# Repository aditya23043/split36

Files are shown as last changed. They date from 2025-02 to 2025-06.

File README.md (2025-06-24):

# 36 Key Split Ergonomic Keyboard

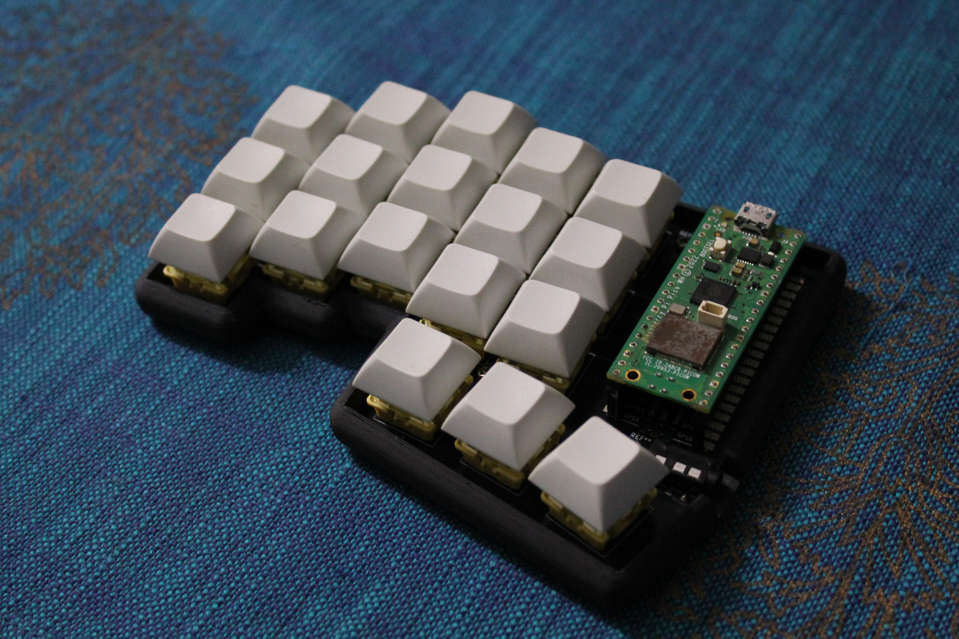
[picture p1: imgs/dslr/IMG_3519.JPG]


## Block Diagram



## BOM

| Item | Qty | Total Price | Ordered From |
| --- | --- | --- | --- |
| PCB | 2 | ₹ 800 | Robu.in |
| 3D printed Cases (optional but recommended) | 2 | ₹ 652 | Robu.in |
| Akko V3 Creamy Yellow Pro Mechanical Switch | 45  | ₹ 999 | StacksKB.com |
| 3.5mm TRRS Jack | 2 | ₹ 28 | Robu.in |
| Raspberry Pi Pico | 2 | ₹ 700 | Robu.in |
| Header 1x40 pin | 2 | ₹ 14.6 | Robu.in |
| High Quality Ultra Flexible 30AWG Silicone Wire - Black | 5 | ₹ 25.00 | Robu.in |
| M2 X 6mm Brass Threaded Inserts (Dia. 2mm, Length 6mm) | 12  | ₹ 26.40 | OnlyScrew.in |
| M2 X 6mm Phillips Pan head SS 304 Screw (Dia. 2mm, Length 6mm) | 12  | ₹ 24.00 | OnlyScrew.in |
| Total | - | ₹ 3269 | |

## Order

<details>
<summary>All the stuff ordered in regards to this project</summary>

> This is not the actual concise BOM\
> All this is just the stuff I ordered related to this project

- StacksKB.com

  - Akko V3 Creamy Yellow Pro Switch (Pack of 45) × 1
  - Order Number: 30456
  - Cost: 899 + 100 (delivery) = ₹ 1000
  - Order Date: 2025-02-08

- Robu.in

| Item | Qty | Cost  |
| --- | --- | ----- |
| TRRS Jack | 2 | ₹ 28  |
| Raspberry Pi Pico | 1 | ₹ 349 |
| Header 1x40 pin | 12  | ₹ 88  |
| Ball Bearing | 2 | ₹ 38  |
| Handling charges  | - | ₹ 25  |
| TOTAL | - | ₹ 528 |

- Robu.in (2nd)

| Item | Qty | Cost |
| --- | --- | --- |
| USB 3.1 Female Socket Type C Connector 24 Pins Breakout PCB Board | 2 | ₹ 98.00 |
| Wire Stripper Flat Nose Cable Cutter with Practical Punch Down Tool | 1 | ₹ 18.00 |
| High Quality Ultra Flexible 30AWG Silicone Wire - Black | 5 | ₹ 25.00 |
| UL1007 26AWG PVC Electronic Wire - Black | 2 | ₹ 14.00 |
| High Quality Ultra Flexible 22AWG Silicone Wire - Black | 2 | ₹ 36.00 |
| Heat Shrink Sleeve 1mm Red Industrial Grade WOER (HST) | 4 | ₹ 20.00 |
| Piezo Buzzer 35mm | 1 | ₹ 16.00 |
| Subtotal: | - | ₹ 227.00 |
| Shipping: | - | ₹ 49.00 via STANDARD SHIPPING |
| Cash Handling Charges: | - | ₹ 25.00 |
| Total: | - | ₹ 301.00 |

- OnlyScrew.in

| Item | Qty | Cost |
| --- | --- | --- |
| M2 X 6mm Brass Threaded Inserts (Dia. 2mm, Length 6mm) | 12  | ₹ 26.40  |
| M2 X 4mm Phillips Pan head SS 304 Screw (Dia. 2mm, Length 4mm) | 12  | ₹ 21.60  |
| M2 X 3mm Brass Threaded Inserts (Dia. 2mm, Length 3mm) | 12  | ₹ 19.20  |
| M2 X 6mm Phillips Pan head SS 304 Screw (Dia. 2mm, Length 6mm) | 12  | ₹ 24.00  |
| M2 Hex Nut SS304 (Dia. 2mm) | 12  | ₹ 19.20  |
| M3 X 12mm Phillips CSK SS 304 Screw (Dia. 3mm, Length 12mm) | 10  | ₹ 16.00  |
| Allen Key 2mm Chromium Vanadium Steel | 1 | ₹ 6.20 |
| M3 X 12mm Hex (Allen) Button Head SS 304 Screw (Dia. 3mm, Length 12mm) | 8 | ₹ 17.60  |
| Subtotal | - | ₹ 150.20 |
| Shipping | - | ₹ 99.00  |
| Taxes | - | ₹ 27.04  |
| Total | - | ₹ 276.24 |

</details>

## Case Designing

- I am aiming for a sandwich case which consists of a bottom part, middle part for padding, another plate in which pcb is resting and the top switch mount plate
- The bottom plate will be of 3mm ABS (non metal laser cut) so that the keyboard has a solid base
- The next plate is the middle one but it is a little bit smaller in inner part so that the PCB can rest on top of it
  - this plate's height will be -> 3mm because we need at least (3.3-1.6) = 1.7mm clearance and having another 1.3mm would be nice so that the soldered wires can go through
  - note: 3.3mm is the distance between the bottom-most point of the MX switch and the point which rests on the PCB
  - and the height of the PCB is 1.6mm
- Next is the other bottom plate with the pcb cutout in the middle so that the pcb can be put into it and also provides the gap between the previous middle layer and the switch mount plate
  - This will be of height -> (5-1.5)+(1.6) = 5.1mm
- Lastly, we have the switch mount plate which obviously holds the MX switches and needs to be 1.5mm in height



## Materials Used for the case (complex case)

| Plate | Material | Cost |
| --- | --- | ---- |
| Bottom | Laser cut Acrylic 3mm |
| Middle | Laser cut Acrylic 3mm |
| Middle v2 | Laser cut Acrylic 5mm |
| Top | ABS FDM 3d printed |

> As of now (025-02-19 23:20), I am pausing this sandwich case idea and shifting to just a single case which encloses the PCB from the bottom and sides\
> I would have preferred to have a switch mount plate as well because it adds stability and reduces dust residue in the keyboard but I would like to get started with a simpler case than the sandwich one and also, I would like to use the existing mounting stuff I have bought i.e. the m2x3mm brass inserts and hence I am heading for this approach

## Simple Case

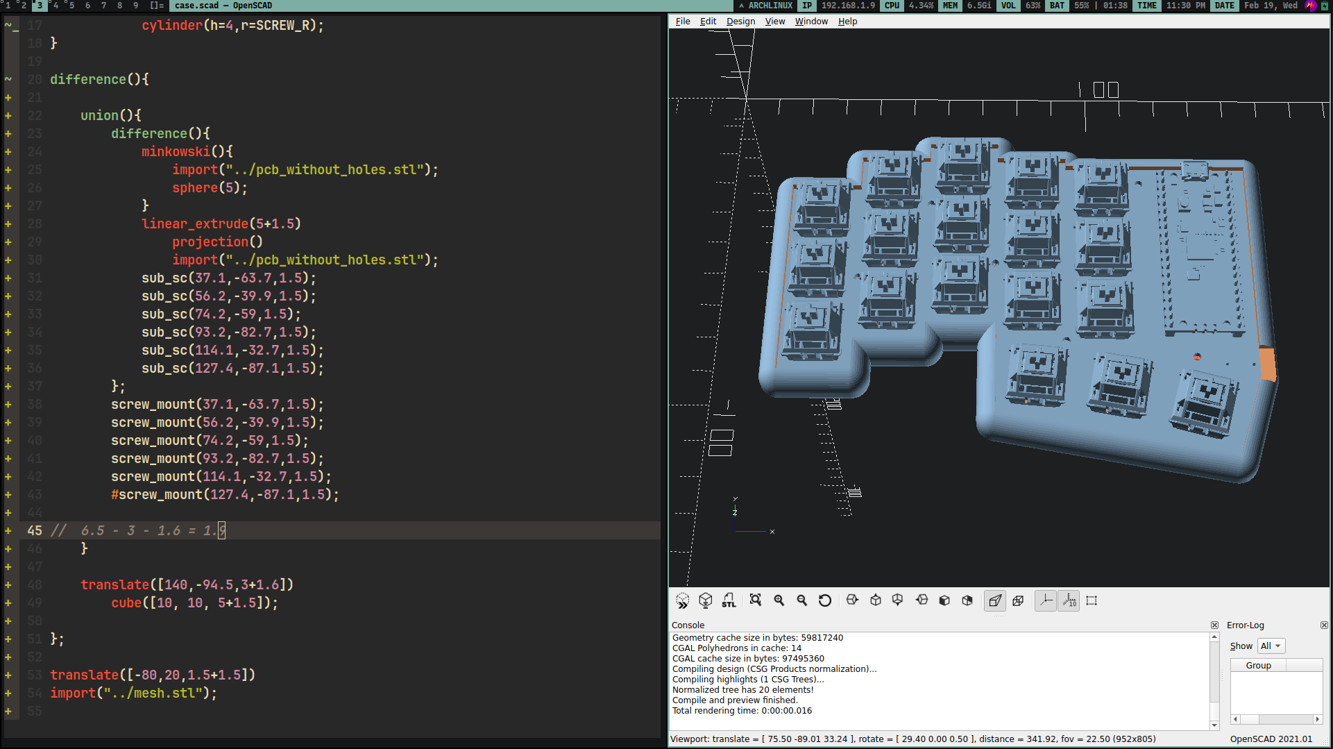
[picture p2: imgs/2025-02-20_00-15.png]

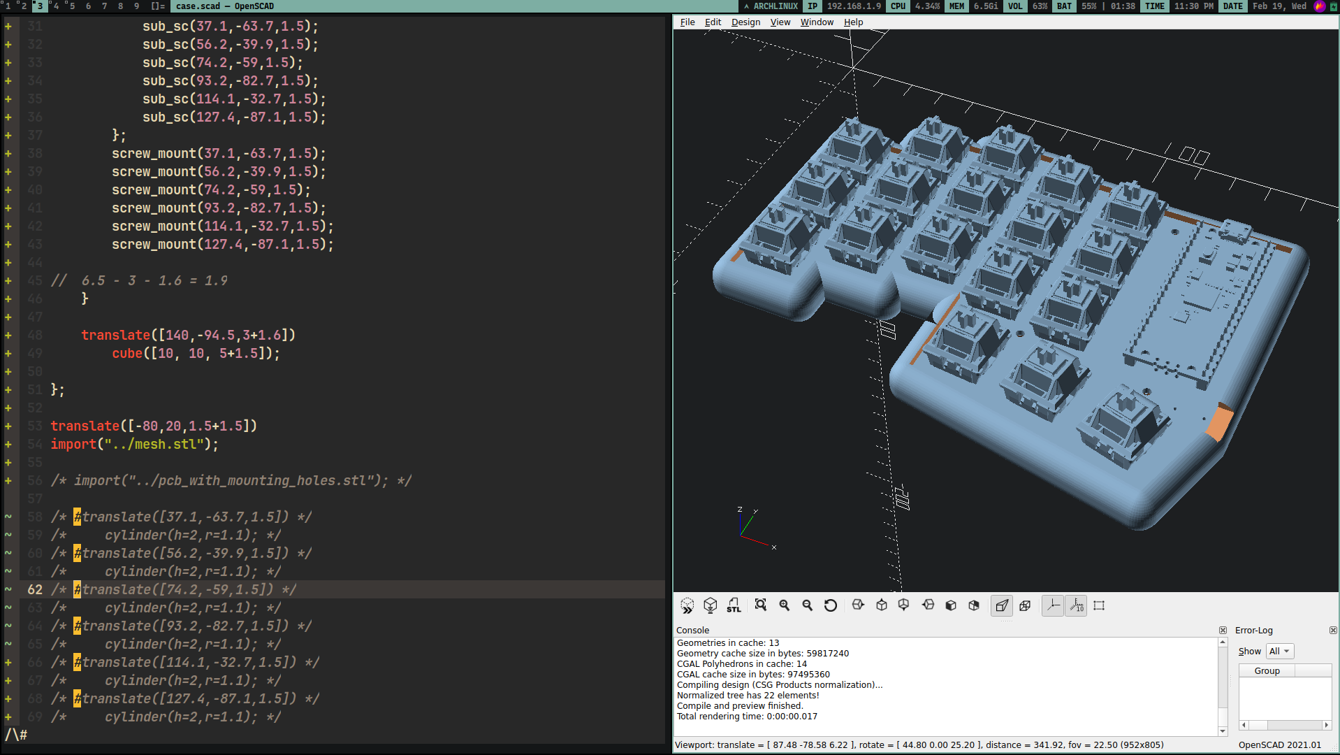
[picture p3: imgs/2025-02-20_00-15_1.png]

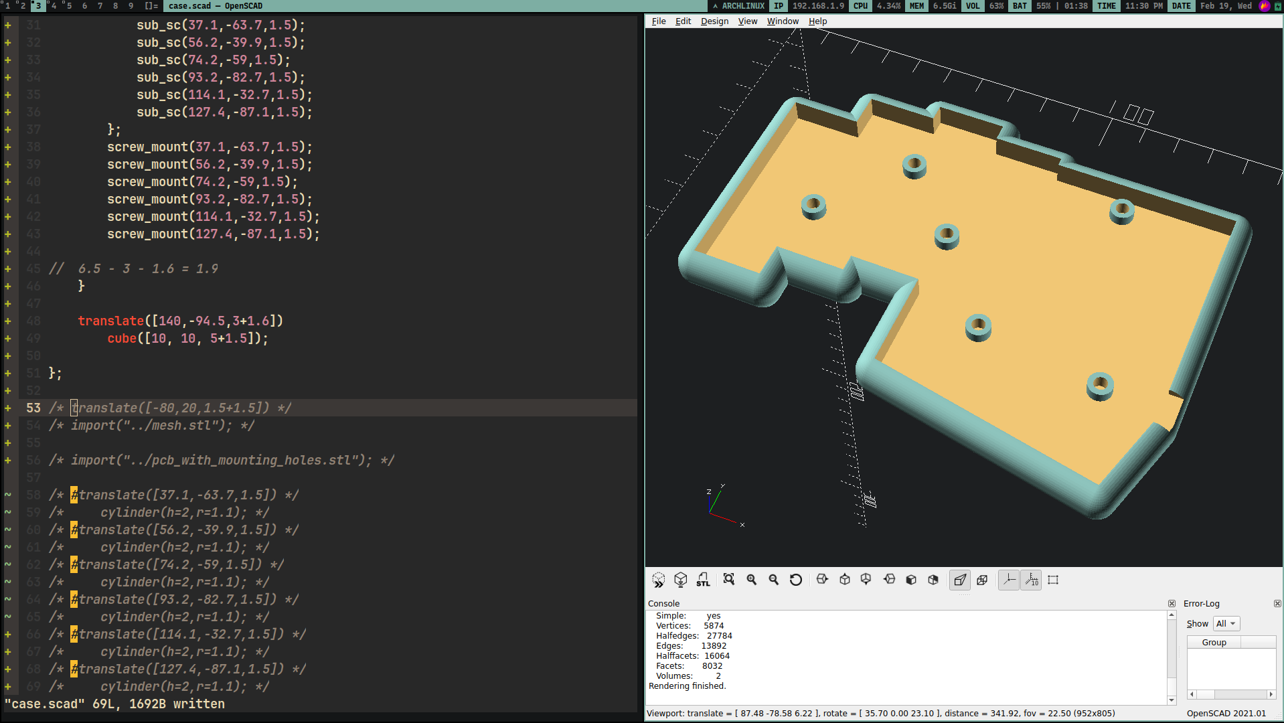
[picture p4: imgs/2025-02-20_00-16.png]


- This case was costing me about Rs. 389 on https://robu.in with ABS and 15% infill
- I believe that is a bit high for me since this is just half of the keyboard
- So, I reduced the cost down to about Rs. 300 by putting the PCB a bit lower and instead of the 5mm solid base, we now have a 2mm solid base which makes a little bit less solid but its not a huge problem
- This is the case with the PCB after the cost cut

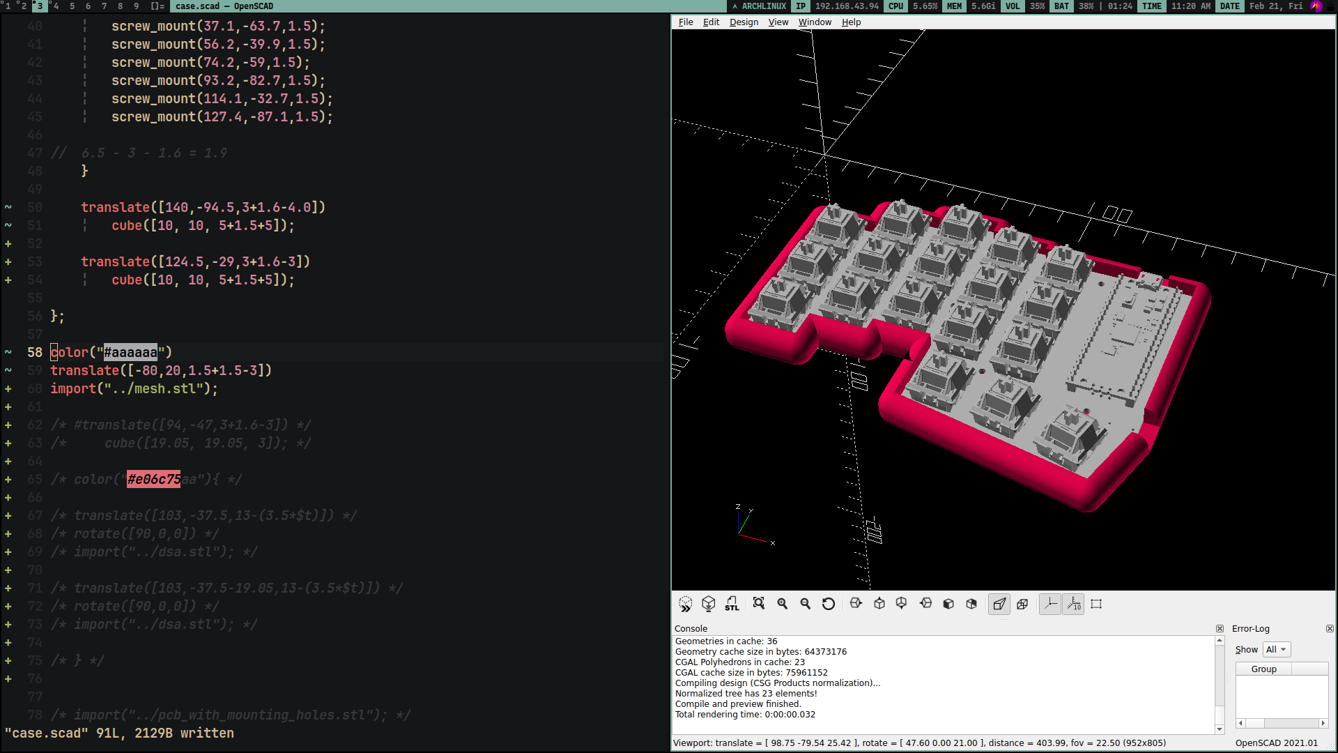
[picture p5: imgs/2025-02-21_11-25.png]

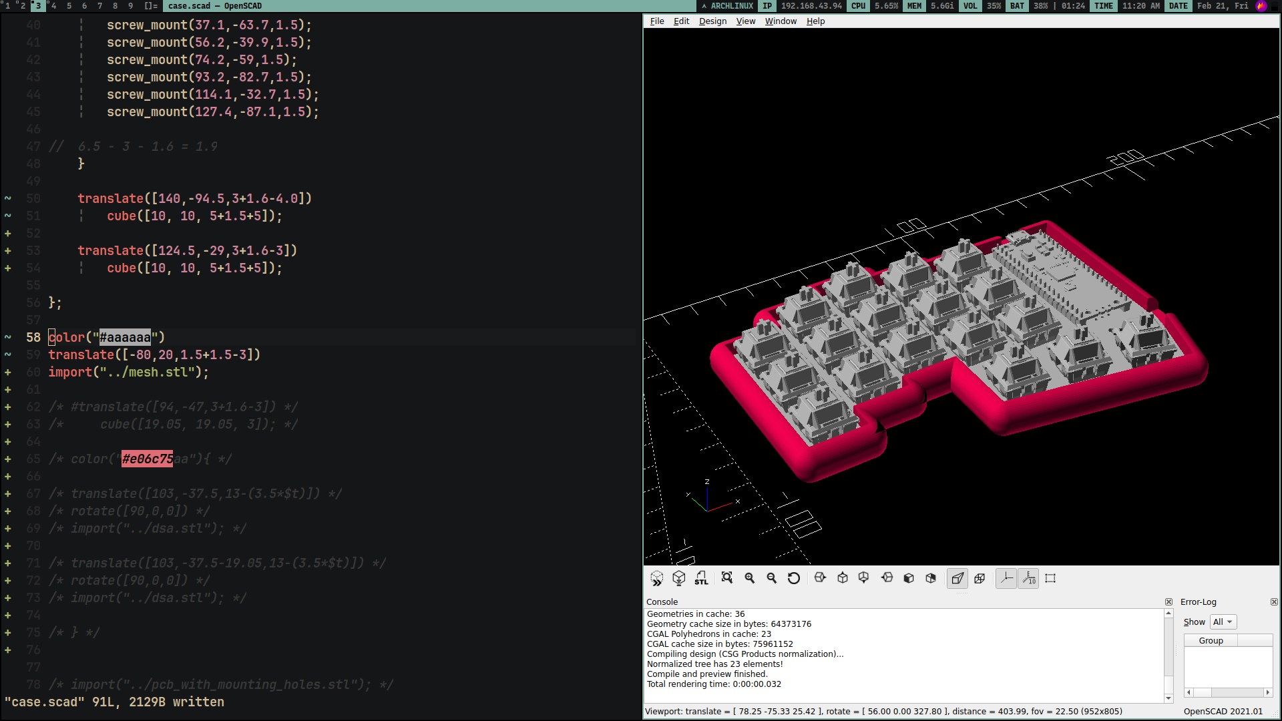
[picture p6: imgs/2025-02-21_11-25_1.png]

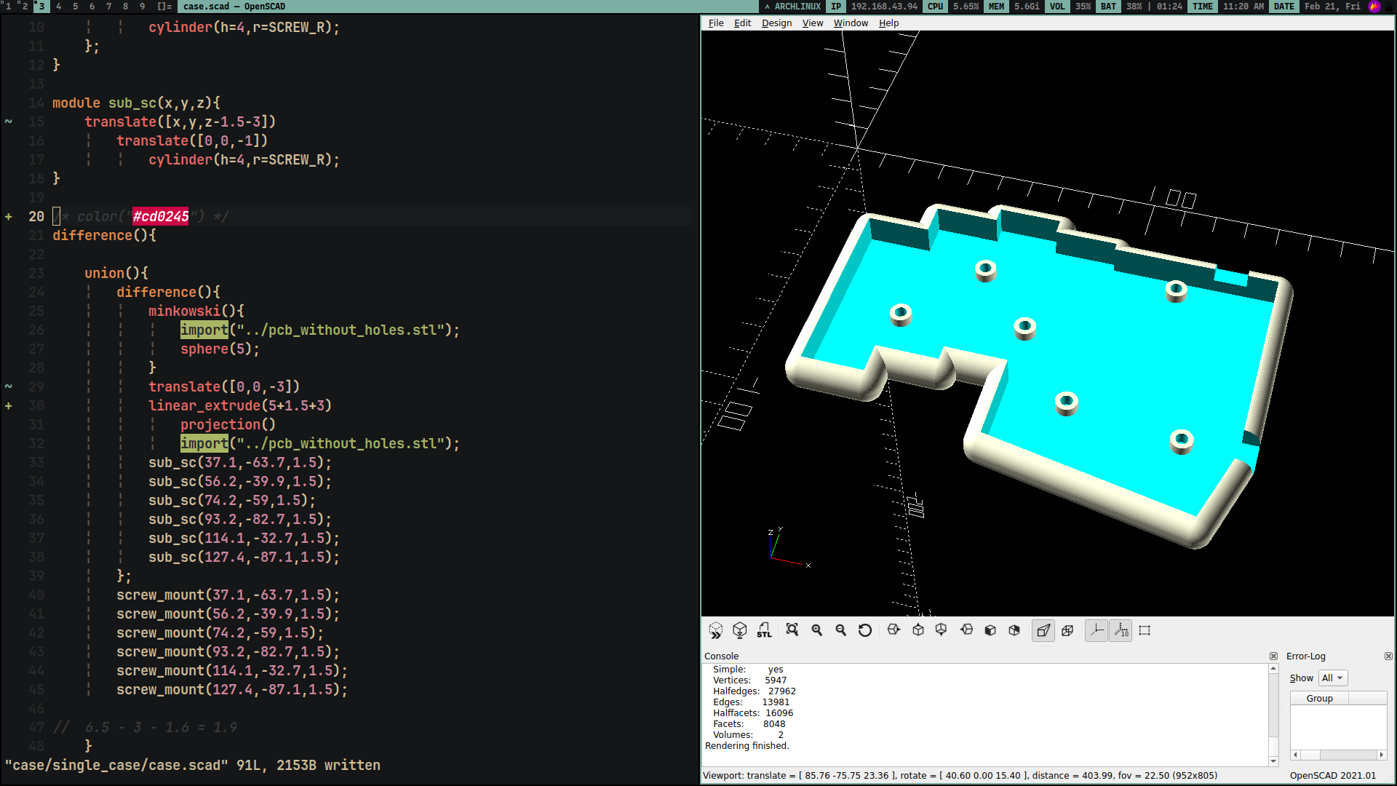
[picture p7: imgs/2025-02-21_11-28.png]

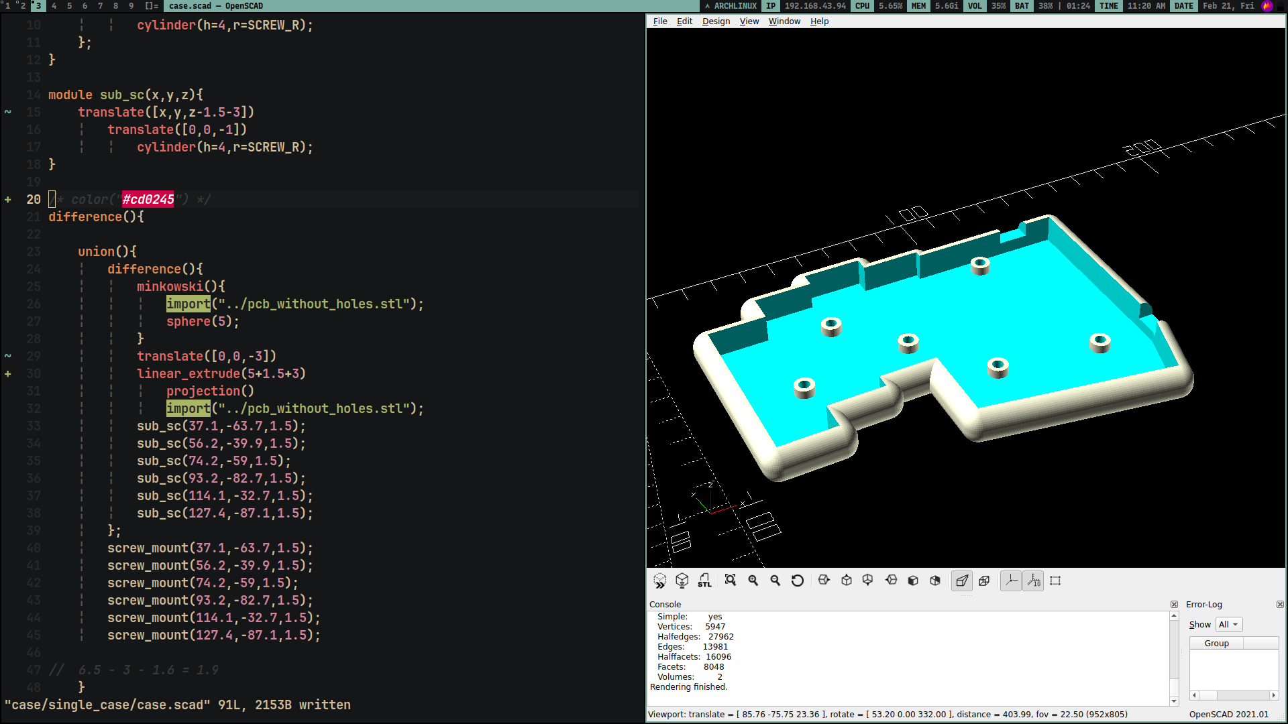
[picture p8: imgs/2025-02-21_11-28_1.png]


- Order placed for this case for Rs.335 along with the mount plate for this project -> https://github.com/aditya23043/Tekken_Controller
- Totalling: Rs. 463 (335 + 79 (mount plate) + 49 (delivery))

## 2025-02-26 23:54

- The case has arrived for one of the halves since I wanted to make sure there were no issues with my design
- And guess what? Yes, there is a major issue with the design
- I had not taken printing error in mind and hence did not account for tolerance issues
- The PCB just wont go in flush. It seems like if the case was just 0.5-1mm more larger on the inside, the PCB would have rested perfectly
- I have updated the 3D case files in the repo to include a 0.7mm clearance on the inside
- As for the case, I have taken suggestions from seniors and batchmates from the Electroholics Club of IIITD
- They have suggested to either use the thermal property of ABS in order to mould it into a bit bigger enclosure
- Or sand the edges down a bit to accomodate the PCB perfectly
- I will be taking the latter approach since that seems more fail proof in my mind
- And hence, I have ordered this sand paper set from amazon -> [Sand paper](https://www.amazon.in/Abrasive-Automotive-Woodworking-Furniture-Finishing/dp/B0CCW1BG6J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)

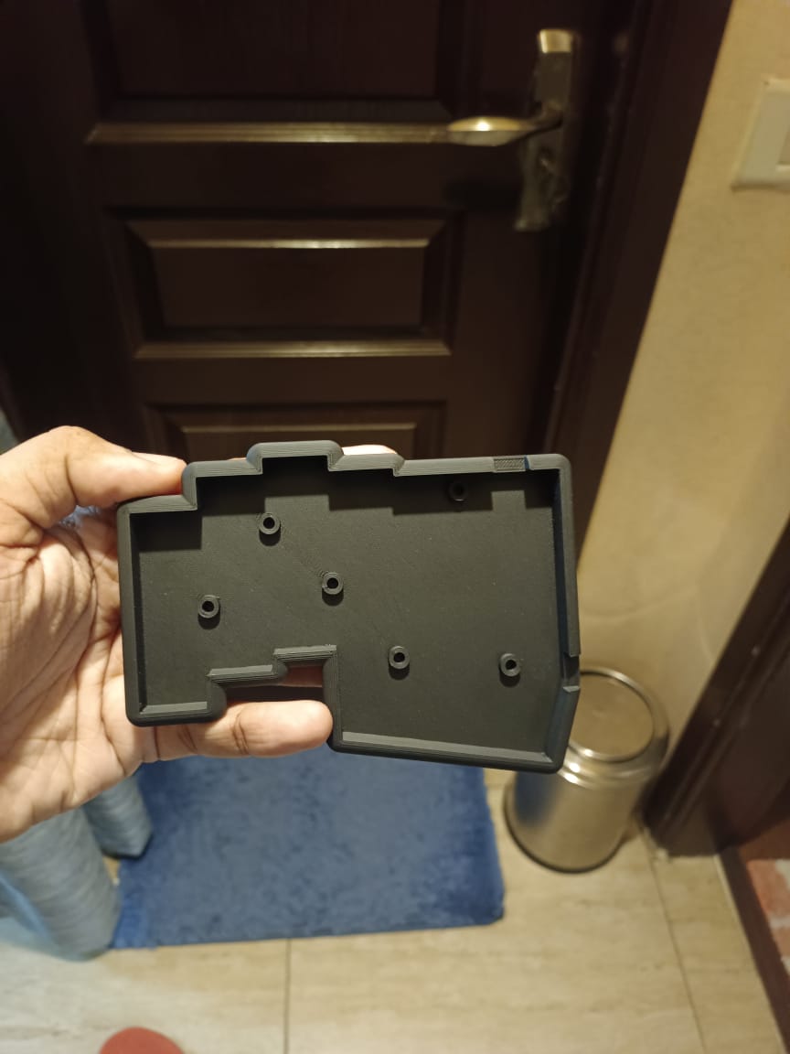
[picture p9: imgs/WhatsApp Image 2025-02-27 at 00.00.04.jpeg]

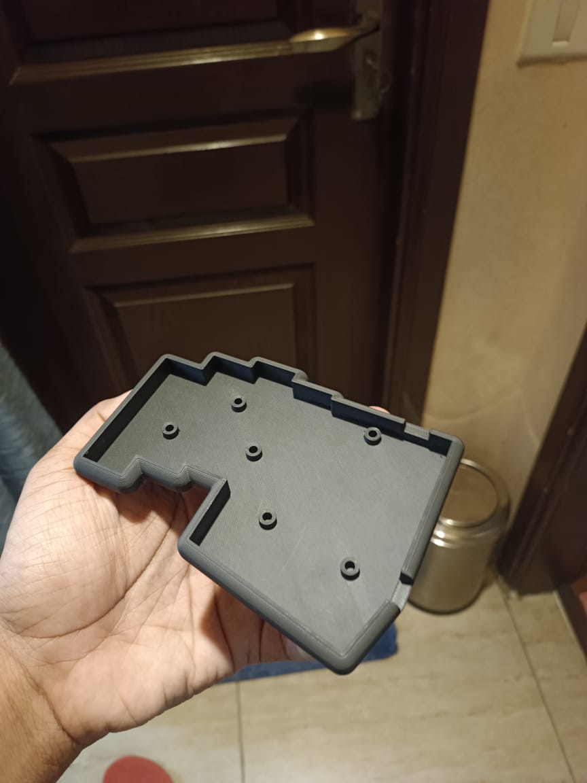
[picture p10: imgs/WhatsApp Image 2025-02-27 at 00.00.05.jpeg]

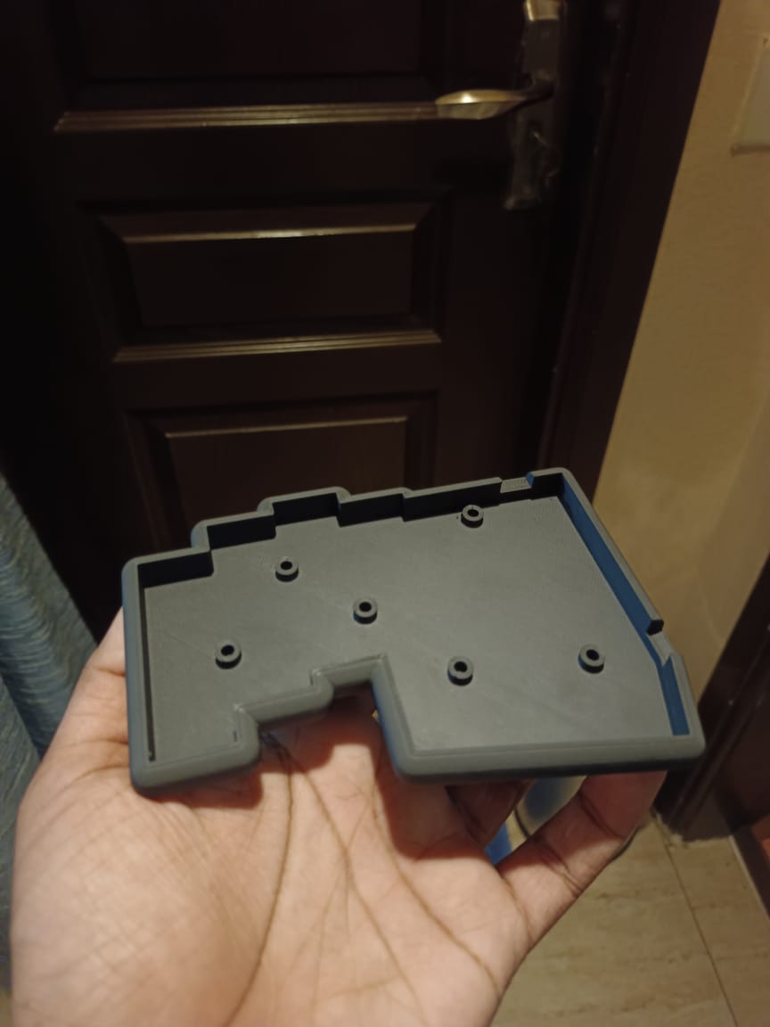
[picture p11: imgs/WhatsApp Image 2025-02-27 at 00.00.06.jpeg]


## 2025-03-18 23:48

- Instead of trying to make do with the case without tolerances, I have decided to add 1mm tolerance to the current design and order it again
- For ABS 15% infill 2mm default nozel, it is costing me Rs. 277 + Rs. 49 = Rs. 326

## 2025-03-29 00:23

- Added brass heat inserts in order to mount the pcb to the case using M2 screws
- Finished soldering the mechanical switches, header pins for MCU and the TRRS jack onto the PCB.

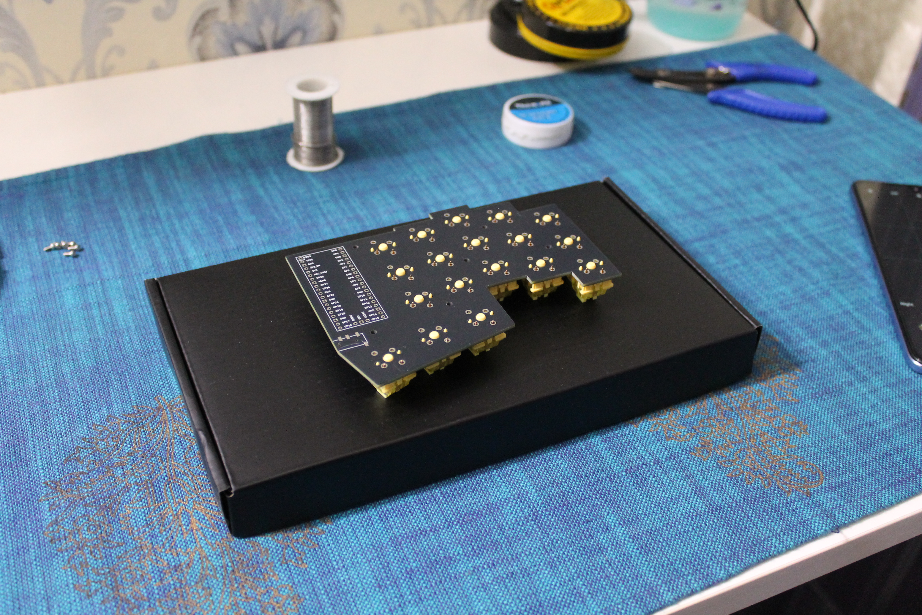
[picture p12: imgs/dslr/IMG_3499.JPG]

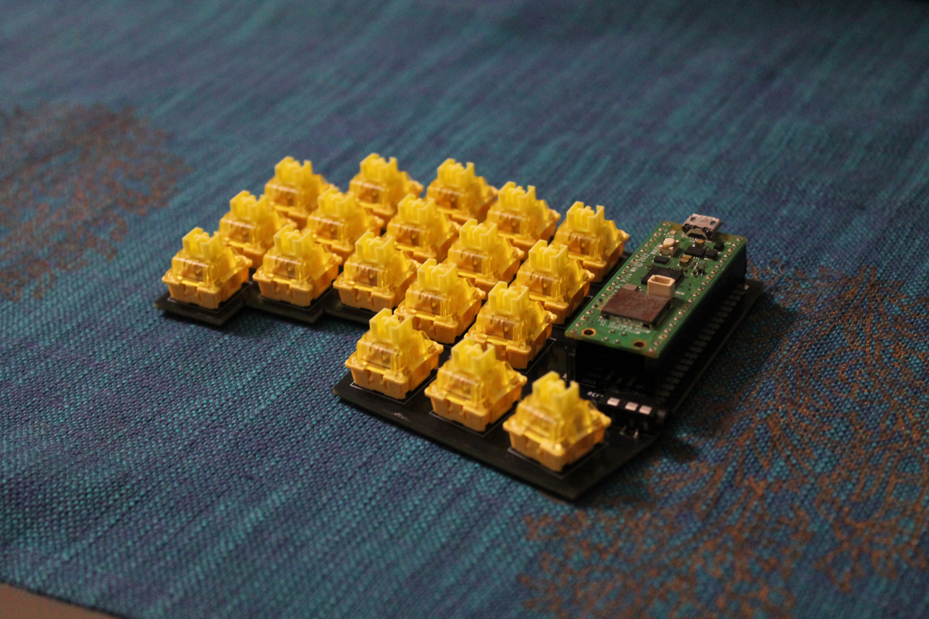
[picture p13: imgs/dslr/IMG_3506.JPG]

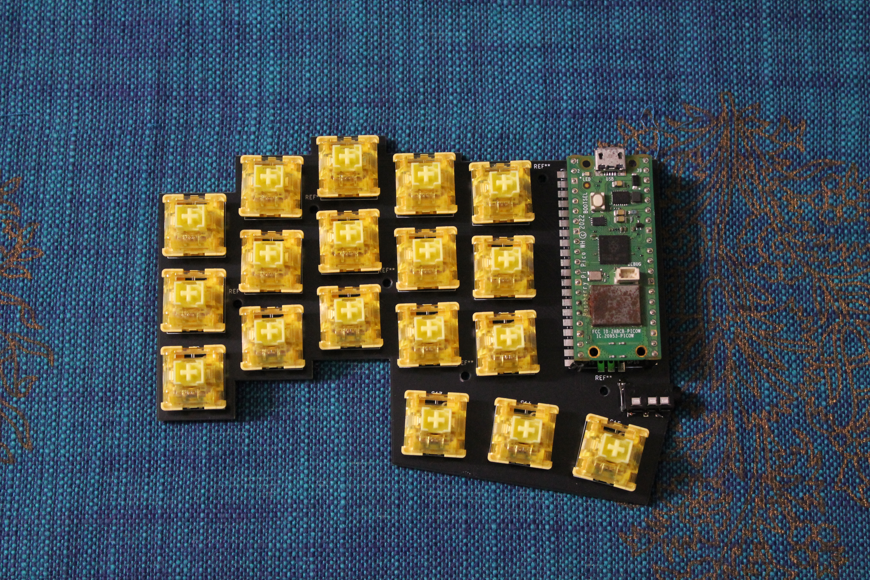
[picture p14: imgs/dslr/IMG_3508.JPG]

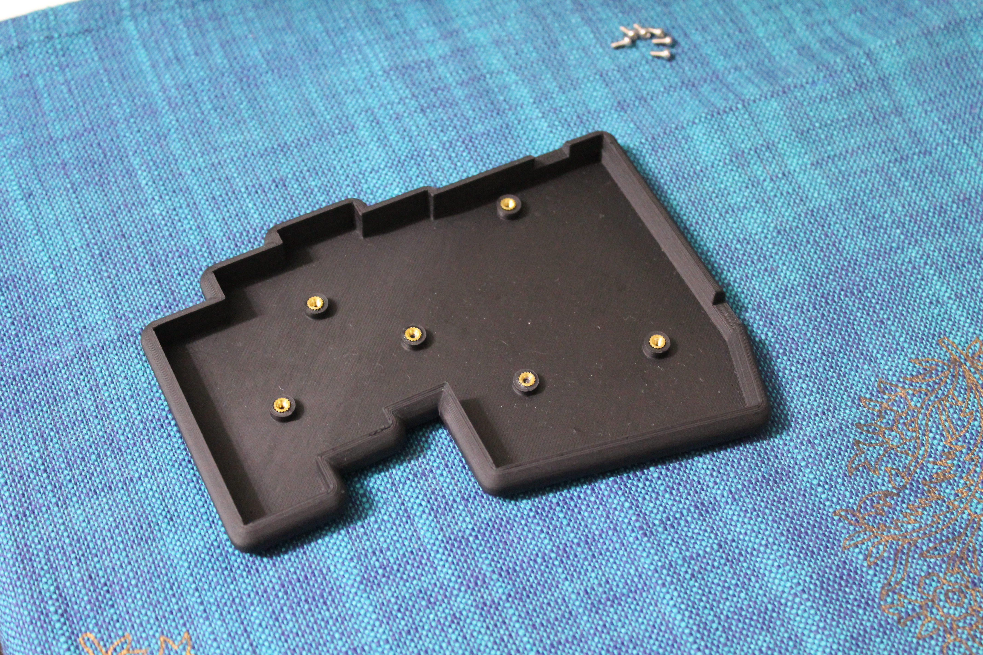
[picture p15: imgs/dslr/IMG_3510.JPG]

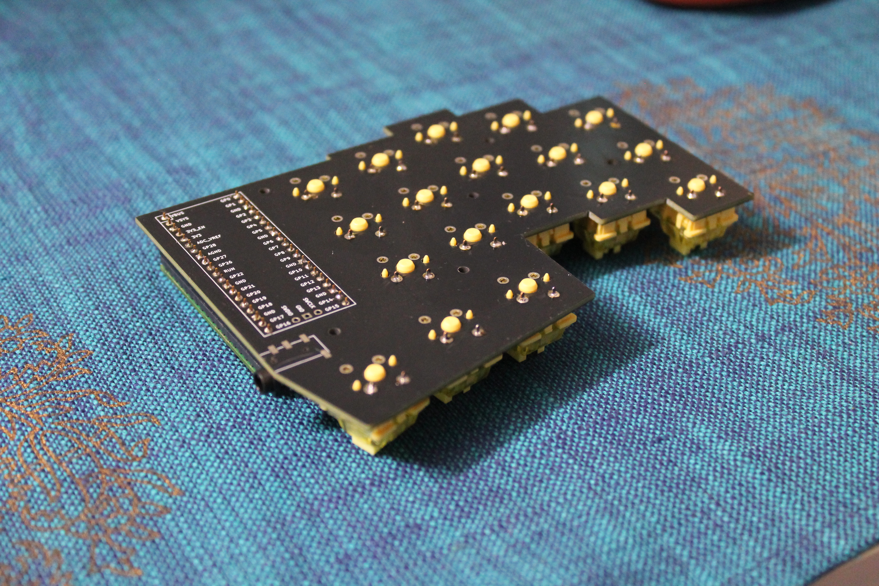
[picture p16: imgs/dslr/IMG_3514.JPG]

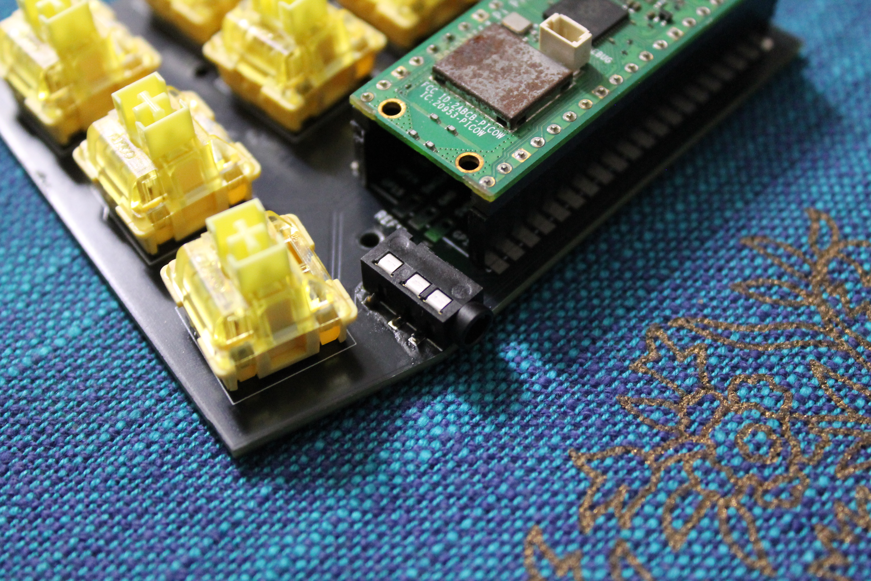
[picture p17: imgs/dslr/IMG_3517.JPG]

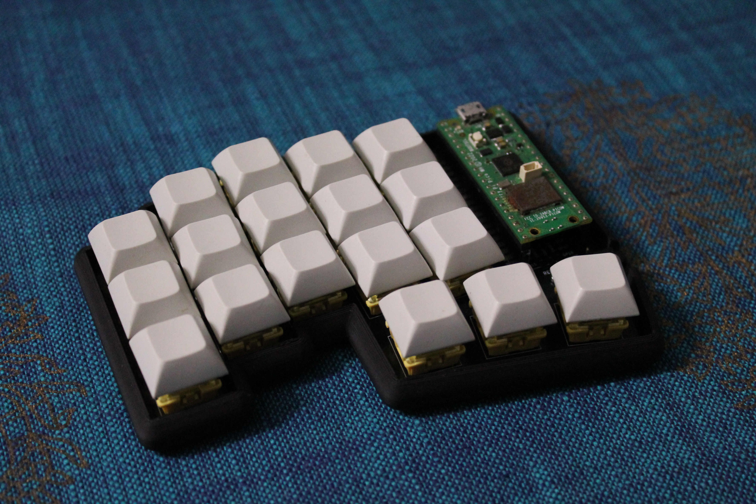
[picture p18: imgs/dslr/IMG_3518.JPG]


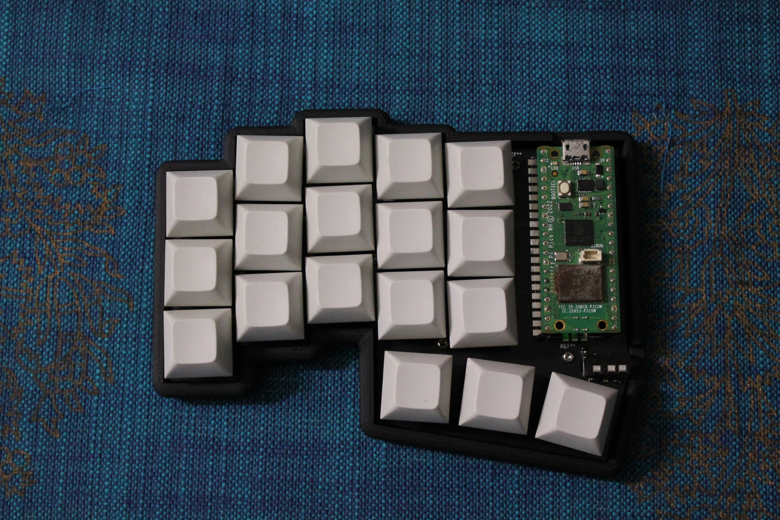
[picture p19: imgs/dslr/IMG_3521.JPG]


## 2025-03-31 23:45

- Deep purple keycaps came in today
- Fixed the skew in keyswitches -> https://www.reddit.com/r/ErgoMechKeyboards/comments/1jmeygr/the_switches_on_my_custom_cornelike_keyboard_do/

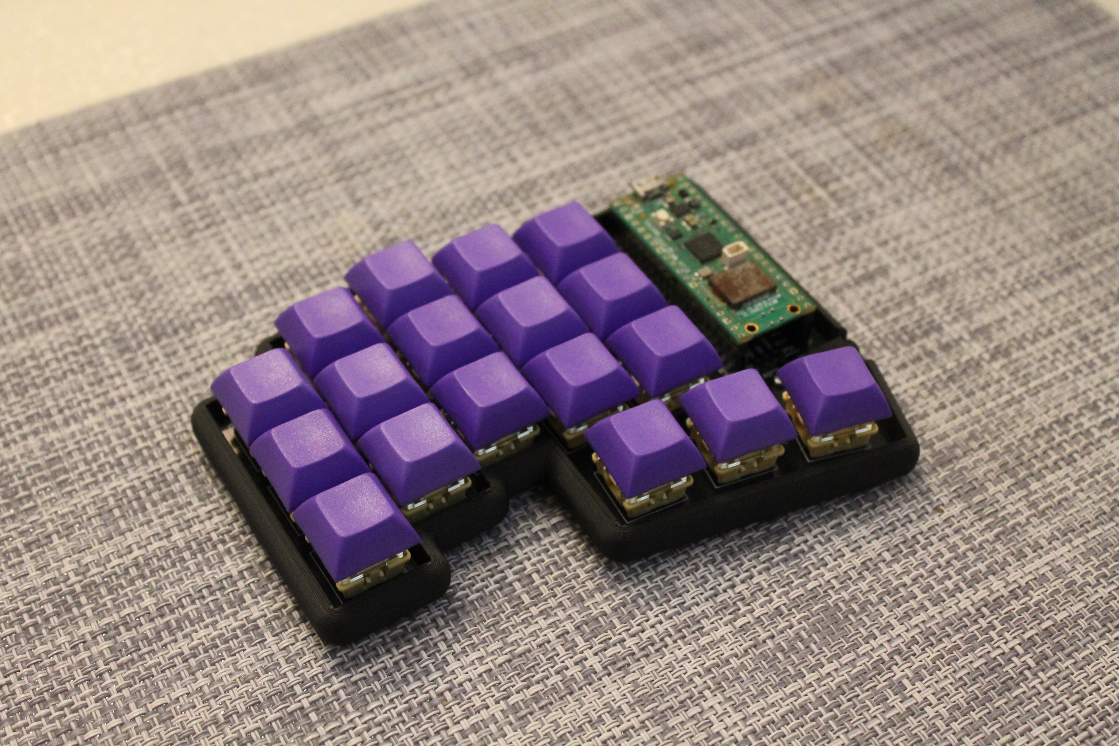
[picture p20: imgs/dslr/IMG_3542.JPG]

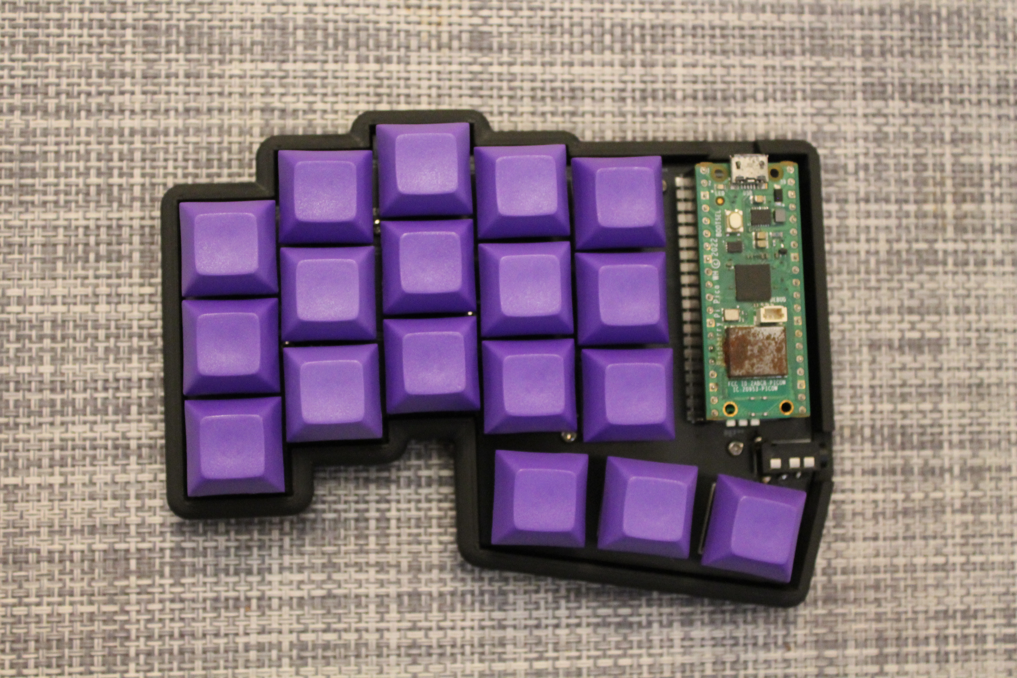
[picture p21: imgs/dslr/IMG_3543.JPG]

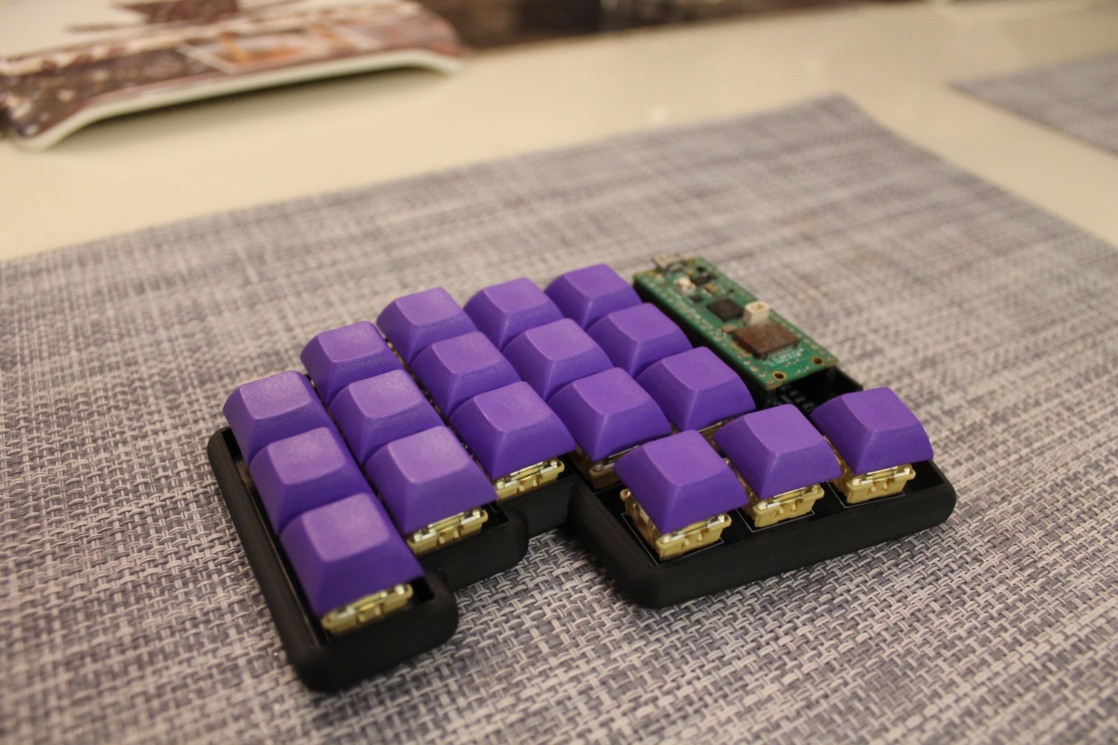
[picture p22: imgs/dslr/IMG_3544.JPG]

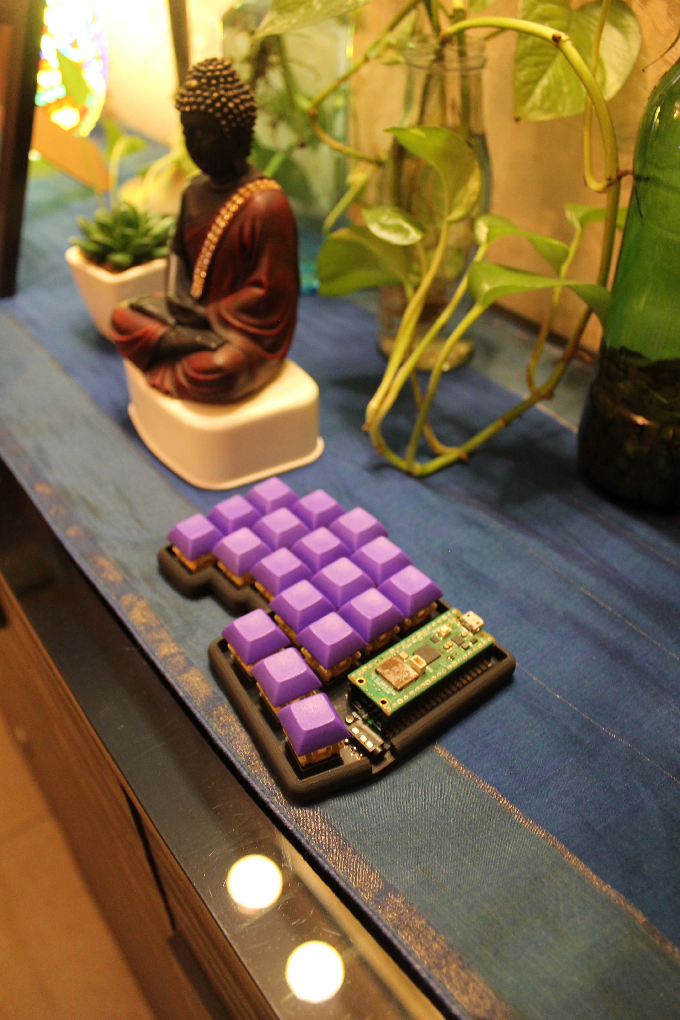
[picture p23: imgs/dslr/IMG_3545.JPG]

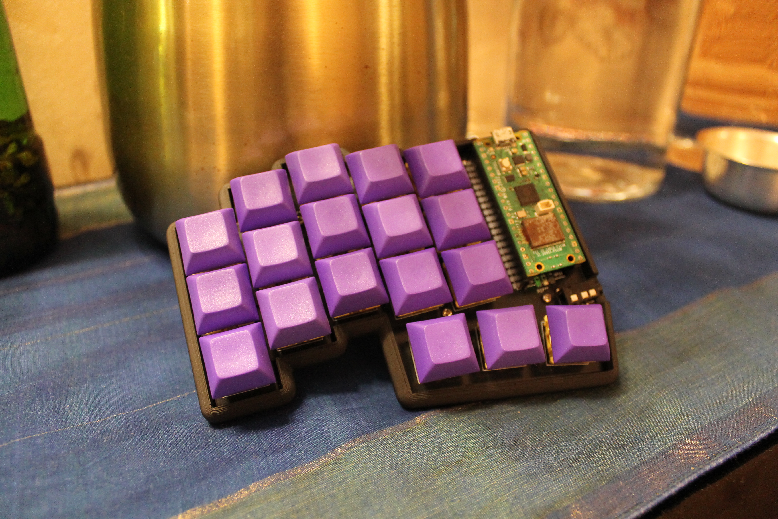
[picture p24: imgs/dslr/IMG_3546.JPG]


## 2025-03-05 10:03

- Case for the right half ordered from https://Robu.in
- Firmware for the left half done
  - Also includes the code for "key held down" event
- [x] Right half assembly
- [ ] Right half firmware

## 2025-04-11 23:13

### Major Issue

- The footprint used for the MX switches (from ScottoKeeb's github repo) had label -> MX 1.00u Reversible written on it. However, it means reversible in the sense that we can swap north facing and south facing switches, not for mutli sided switches
- Hence, the assembly of the right half is on hold until the new PCB arrives.
- In the modified kicad project I have used the SW_MX_REVERSIBLE footprint from -> https://github.com/daprice/keyswitches.pretty
- Furthermore, I have added the kicad project in this repo inside the `pcb/` directory
- 2025-04-11 23:26 -> PCB order placed
  - Cost: ₹1935 for 5 PCBs
  - Nearly: ₹400 per PCB

## 2025-05-03 23:13

- Right Half assembly done

## Major Issue 2.0

- The TRRS jack connection on the second half is technically correct but the problem is that since the right half is just the flip of left half PCB, the microcontroller should either be soldered reverse or else the pins are flipped wrt the vertical axis
- Due to this, the connections of the TRRS jack are reversed as well
- Instead of GND, VSYS, GP0, GP1; we have -> GND, GP1, VBUS, VSYS which is very wrong in context of the code logic
- Hence, I had to scratch out all the copper tracks manually connected to the TRRS jack and connect them with the MCU manually using wires with the following connections

```
TRRS
4 3 2
    1

DEFAULT
1 GND
2 GP1
3 VBUS
4 VSYS

WHAT WE WANT
1 GND
2 VSYS
3 GP0 (SDA)
4 GP1 (SCL)
```

- And finally, with testing, I am able to confirm that the right half can now be powered properly with just the left half connected with the system
- So, as of now, this prototype's hardware stuff has been completed
- [X] TODO: Firmware

WhatsApp Image 2025-05-03 at 23 23 26
WhatsApp Image 2025-05-03 at 23 23 26(1)
WhatsApp Image 2025-05-03 at 23 23 26(2)
WhatsApp Image 2025-05-03 at 23 23 29
WhatsApp Image 2025-05-03 at 23 23 30

# Finished the project! 
- Presentation: https://docs.google.com/presentation/d/1XDV15suqviizSQfUHfM2_ha1iqeUGhER_RJtFe0Dyr4/edit?usp=sharing
- LinkedIn Post: https://www.linkedin.com/posts/aditya23043_just-completed-my-most-ambitious-project-activity-7335380768921198593-B5wh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

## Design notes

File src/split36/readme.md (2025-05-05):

# split36

split36

*A short description of the keyboard/project*

* Keyboard Maintainer: [Aditya Gautam](https://github.com/aditya23043)
* Hardware Supported: *The PCBs, controllers supported*
* Hardware Availability: *Links to where you can find this hardware*

Make example for this keyboard (after setting up your build environment):

    make split36:default

Flashing example for this keyboard:

    make split36:default:flash

See the [build environment setup](https://docs.qmk.fm/#/getting_started_build_tools) and the [make instructions](https://docs.qmk.fm/#/getting_started_make_guide) for more information. Brand new to QMK? Start with our [Complete Newbs Guide](https://docs.qmk.fm/#/newbs).

## Bootloader

Enter the bootloader in 3 ways:

* **Bootmagic reset**: Hold down the key at (0,0) in the matrix (usually the top left key or Escape) and plug in the keyboard
* **Physical reset button**: Briefly press the button on the back of the PCB - some may have pads you must short instead
* **Keycode in layout**: Press the key mapped to `QK_BOOT` if it is available

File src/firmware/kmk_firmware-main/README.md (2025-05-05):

# KMK: Clackety Keyboards Powered by Python






KMK is a feature-rich and beginner-friendly firmware for computer keyboards
written and configured in
[CircuitPython](https://github.com/adafruit/circuitpython).

## Support

For asynchronous support and chatter about KMK, [join our Zulip
community](https://kmkfw.zulipchat.com)!

If you ask for help in chat or open a bug report, if possible
make sure your copy of KMK is up-to-date.
In particular, swing by the Zulip chat *before* opening a GitHub Issue about
configuration, documentation, etc. concerns.

> The former Matrix and Discord rooms once linked to in this README are no
> longer officially supported, please do not use them!

## Features

- Fully configured through a single, easy to understand Python file that lives
  on a "flash-drive"-esque space on your microcontroller - edit on the go
  without DFU or other dev tooling available!
- Single-piece or [two-piece split
  keyboards](/docs/en/split_keyboards.md)
  are supported
- [Chainable
  keys](/docs/en/keys.md) such as
  `KC.LWIN(KC.L)` to lock the screen on a Windows PC
- [Built-in Unicode macros, including
  emojis](/docs/en/macros.md)
- [RGB underglow](/docs/en/rgb.md)
  and [LED
  backlights](/docs/en/led.md)
- One key can turn into many more based on [how many times you tap
  it](/docs/en/tapdance.md)
- Bluetooth HID and split keyboards. No more wires.

## Getting Started
KMK requires [CircuitPython](https://circuitpython.org/) version 7.0 or higher.
Our getting started guide can be found
[here](/docs/en/Getting_Started.md).

## Contributing

Please have a look at the [contributing document](/docs/en/contributing.md), 
where you can find details about the workflow and code style. If you have 
specific questions feel free to ask in the [KMK development stream](https://kmkfw.zulipchat.com/#narrow/stream/384078-KMK-development) 
on Zulip.

## License, Copyright, and Legal

All software in this repository is licensed under the [GNU Public License,
version 3](https://tldrlegal.com/license/gnu-general-public-license-v3-(gpl-3)).
All documentation and hardware designs are licensed under the [Creative Commons
Attribution-ShareAlike 4.0](https://creativecommons.org/licenses/by-sa/4.0/)
license.

**Due to ethical and legal concerns, any works derived from GitHub Copilot or
similar artificial intelligence tooling are unacceptable for inclusion in any
first-party KMK repository or other code collection. We further recommend not
using GitHub Copilot while developing anything KMK-related, regardless of
intent to submit upstream.**

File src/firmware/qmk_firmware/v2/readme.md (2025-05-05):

# cantor

cantor

The Cantor keyboard is a 42 key diodeless split keyboard, designed with simplicity in mind. It is inspired on the popular [corne](https://github.com/foostan/crkbd), [ferris](https://github.com/pierrechevalier83/ferris) and [sweep](https://github.com/davidphilipbarr/Sweep) keyboards, aiming to provide a more ergonomic (stronger column stagger) corne-like layout with a simple, easy to assemble and cheap design.

* Keyboard Maintainer: [Diego Palacios](https://github.com/diepala)
* Hardware Supported: Blackpill STM32F401
* Hardware Availability: https://github.com/diepala/cantor

Make example for this keyboard (after setting up your build environment):

    make cantor:default

Flashing example for this keyboard:

    make cantor:default:flash

See the [build environment setup](https://docs.qmk.fm/#/getting_started_build_tools) and the [make instructions](https://docs.qmk.fm/#/getting_started_make_guide) for more information. Brand new to QMK? Start with our [Complete Newbs Guide](https://docs.qmk.fm/#/newbs).

## Bootloader

Enter the bootloader in 3 ways:

* **Bootmagic reset**: Hold down the top left key and plug in the keyboard. For the right side, hold the top right key and plug the keyboard.
* **Physical reset button**: 
  * Press and hold the BOOT0 button.
  * Press and release the NRST button.
  * Release the BOOT0 button.
* **Keycode in layout**: Press the key mapped to `QK_BOOT` if it is available

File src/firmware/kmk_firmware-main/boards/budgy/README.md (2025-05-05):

# Budgy Keyboard Rev 1
Split 34 key keyboard powered by a Raspberry Pi Pico and diode-less.

Budgy

Keyboard created by [Alex Miller](https://github.com/doesntfazer)
Keyboard build guide at: [Build Guide](https://github.com/doesntfazer/Budgy/blob/main/Build%20Guides/readme.md)
KMK config created by [Jakob Edvardsson](https://github.com/JakobEdvardsson)

## Layout
This config has both US-qwerty and Swedish-Colemak-DH in mind.
The default keymap is US-qwerty, in order to switch to the Swedish-Colemak-DH keymap,
comment out the US-qwerty keymap and uncomment the Swedish-Colemak-DH keymap in the main.py file.

US-qwerty layer:
```python
#import keymap_sw as keymap  
import keymap_us as keymap
```

Swedish-Colemak-DH layer:
```python
import keymap_sw as keymap
#import keymap_us as keymap
```

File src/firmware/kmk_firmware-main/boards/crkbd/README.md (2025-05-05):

# Corne Keyboard (CRKBD)

Crkbd

Crkbd

A split keyboard with a 3x6 columnar stagger and 3 thumb keys.

Hardware Availability: [PCB & Case Source](https://github.com/foostan/crkbd)  

Extensions enabled by default  
- [Layers](/docs/en/layers.md) Need more keys than switches? Use layers.
- [RGB](/docs/en/rgb.md) Light it up
- [BLE_Split](/docs/en/split_keyboards.md) Connects halves without wires

Common Extensions
- [Split](/docs/en/split_keyboards.md) Connects halves using a wire
- [Power](/docs/en/power.md) Powersaving features for battery life

## Microcontroller support

Update this line in `kb.py` to any supported microcontroller in `kmk/quickpin/pro_micro`:

```python
from kmk.quickpin.pro_micro.boardsource_blok import pinout as pins
```

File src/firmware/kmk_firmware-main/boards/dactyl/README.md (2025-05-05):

# Dactyl

Dactyl1
Dactyl2

A split body, concave shaped keywell, columnar keyboard with a 6 key thumb cluster that takes inspiration from the Kinesis Advantage keyboard range.

Hardware Availability: [Case Files](https://github.com/adereth/dactyl-keyboard)

KMK's rendition of the Dactyl requires two micro controllers rather than the original implementation of a micro controller and I/O expander. 

## Case Files Generator

[Dactyl Generator](https://ryanis.cool/dactyl), created by [rianadon](https://github.com/rianadon), is a web based file generator that negates composing case files using a programming language, which was a requirement when using the GitHub repository for this board, by instead compiling case files based on options and parameters configured in a web front end.

## KMK Specifics

Extensions enabled by default  
- [Layers](/docs/en/layers.md)
- [Split](/docs/en/split_keyboards.md): Configured to 1-wire UART to match legacy configuration. Please see documentation for enabling 2-wire UART or, for capable controllers, Bluetooth

## Microcontroller support

Replace `kb2040` in the following line of `kb.py` to a supported microcontroller listed in `kmk/quickpin/pro_micro`:

```python
from kmk.quickpin.pro_micro.kb2040 import pinout as pins
```

## Dactyl CC & Ergo S-1

Electronically:
1. [Dactyl CC](https://github.com/mjohns/dactyl-cc) and [Ergo S-1](https://github.com/wizarddata/Ergo-S-1) are identical to one another
2. Both these boards are identical to the Dactyl with one difference; on the finger keywell, they do not have the bottom row, outer column key (per half) of the Dactyl

To accommodate this, in files:
- **`kb.py`**  
`coord_mapping` element: Delete '`24, `' and '`65,`'
- **`main.py`**  
`keyboard.keymap` element: Delete bottom row, outer column position from each side including accompanying comma

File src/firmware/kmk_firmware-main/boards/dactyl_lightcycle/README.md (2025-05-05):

# Dactyl LightCycle

Dactyl LightCycle

A handwired, split body, concave shaped keywell, columnar keyboard -- the Dactyl LightCycle is a variation of the [Dactyl](/boards/dactyl/) keyboard.  
Differences from the Dactyl are:
1. Top (number) row removed
2. Thumb cluster is 5 keys, down from 6

[Case Files](https://github.com/adereth/dactyl-keyboard/tree/master/things): Files, in linked GitHub directory, with name beginning "LightCycle" are applicable.

KMK's rendition of the Dactyl LightCycle requires two micro controllers, rather than the Dactyl's original implementation of a micro controller and I/O expander. 

## Case Files Generator

[Dactyl Generator](https://ryanis.cool/dactyl), created by [rianadon](https://github.com/rianadon), is a web based file generator that negates composing case files using a programming language, which was a requirement when using the GitHub repository for this board, by instead compiling case files based on options and parameters configured in a web front end.

## KMK Specifics

Extensions enabled by default:
- [Layers](/docs/en/layers.md)
- [Split](/docs/en/split_keyboards.md): Configured to 1-wire UART to match legacy configuration. Please see documentation for enabling 2-wire UART or, for capable controllers, Bluetooth
- [HoldTap](/docs/en/holdtap.md)

## Microcontroller support

Replace `kb2040` in the following line, of `kb.py` file, to a supported microcontroller listed in `kmk/quickpin/pro_micro`:

```python
from kmk.quickpin.pro_micro.kb2040 import pinout as pins
```

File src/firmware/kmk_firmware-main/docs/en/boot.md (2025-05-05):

# boot.py
`boot.py` lives in the root of your keyboard when mounted as a storage device.
There is a more detailed explanation in the [CircuitPython Documentation](https://docs.circuitpython.org/en/latest/README.html),
however there are some common use cases for your keyboard listed on this page.

## KMK's builtin boot configurator

KMK ships with a handy boot configuration function that does all the hard work
for you.
The interface may change in the future, but there is a safety mechanism in
place: if anything goes wrong, it'll boot into a mountable and debuggable
configuration.

### Signature

```python
from kmk.bootcfg import bootcfg

bootcfg(
    # optional:
    sense: Optional[microcontroller.Pin, digitalio.DigitalInOut] = None,
    source: Optional[microcontroller.Pin, digitalio.DigitalInOut] = None,
    autoreload: bool = True,
    boot_device: int = 0,
    cdc_console: bool = True,
    cdc_data: bool = False,
    consumer_control: bool = True,
    keyboard: bool = True,
    midi: bool = True,
    mouse: bool = True,
    nkro: bool = False,
    pan: bool = False,
    six_axis: bool = False,
    storage: bool = True,
    usb_id: Optional[dict] = {},
    **kwargs,
) -> bool
```
All optional parameters are set to reflect common CircuitPython defaults, however
they may differ from board specific defaults.

#### `sense`
`sense` accepts either uninitialized `Pin`s or `DigitalInOut` instances for
maximum flexibility.
The lockout-prone subset of boot configuration is only applied if `sense` reads `True` or "high", and
skipped if it reads `False` or "low". The latter is also true if `sense` is not provided.
If `sense` is an uninitialized `Pin`, it'll be configured as pulled-up input; it
wont be further configured if it is a `DigitalInOut`.

#### `source`
`source` accepts either uninitialized `Pin`s or `DigitalInOut` instances for
maximum flexibility.
It's the "source" of the test voltage to be read by the sense pin.
If `source` is an uninitialized `Pin`, it'll be configured as a "low" output; it
wont be further configured if it is a `DigitalInOut`.

Common matrix and direct pin configurations (see also the examples below):

|diode_orientation |sense pin  |source pin |
|---|---|---|
|`COL2ROW` |column |row |
|`ROW2COL` |row |column |
|direct pin |direct pin |`None` |

#### `autoreload`
CircuitPython will automatically reload when any data or meta data is written to
the CircuitPython drive.
Certain operating systems tend to do that without asking; in that case
`autoreload` can be disabled as a workaround.

#### `boot_device`
Boot HID device configuration for `usb_hid`, see the [`usb_hid` documentation](https://docs.circuitpython.org/en/latest/shared-bindings/usb_hid/index.html#usb_hid.enable)
for details.

#### `cdc_console`
This will enable or disable the USB endpoint for the serial console with REPL.
**Caution**: If erroneous `sense` parameter is provided, changing this might make recovery problematic.

#### `cdc_data`
This will enable or disable the USB endpoint for the data serial.

#### `consumer_control`
Enable the HID endpoint for consumer control reports. Those are extra keys for
things like multimedia control and browser shortcuts.

#### `keyboard`
Enable the keyboard HID endpoint. Why would you disable that? For a split half
that isn't connected to USB and needs extra memory for a massive display maybe?

#### `midi`
It's MIDI over USB. Enabled by default in CircuitPython, but most keyboards don't use it.

#### `mouse`
Enable the HID endpoint for a pointing device. A pointing device, or mouse, is
like a keyboard, but with continuous instead of binary keys... which also go
sideways.

#### `nkro`
Enable n-key rollover support. If the default keyboard is enabled, this option
will replace the standard 6-key rollover endpoint with an n-key rollover one.
This is technically not a standard HID endpoint, but if you want this, you
probably know what you're doing.

#### `pan`
Enable panning, aka horizontal scrolling, for the pointing device, aka mouse,
hid endpoint.

#### `six_axis`
Enable a HID endpoint for a six-axis SpaceMouse (with range +/-500) and change
the VID/PID to a SpaceMouse Compact.

#### `storage`
Disable storage if you don't want your computer to go "there's a new thumb drive
I have to mount!" every time you plug in your keyboard.
**Caution**: If erroneous `sense` parameter is provided, changing this might make recovery problematic.

#### `usb_id`
A recent addition to CircuitPython 8 is the ability to give your keyboard an
identity other than "MCU board manufacturer" - "CircuitPython device".
The argument is expected to be a kwargs-dictionary that is passed to
`supervisor.set_usb_identification`.
See the example 1 and the [CircuitPython documentation](https://docs.circuitpython.org/en/latest/shared-bindings/supervisor/index.html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) for reference.

#### return value
`bootcfg` returns `true` if boot configuration applied successfully and `false`
if it was skipped, in case you want to use the sense pin mechanism for other
custom boot configurations.
Any *unexpected* errors are intentionally not handled, in order to be recorded
to the `boot_out.txt` file for easier debugging.

### Example 1
* diode direction from columns to rows,
* disabled storage
* disabled midi
* disabled mouse
* custom vendor and device names

```python
import board

from kmk.bootcfg import bootcfg

bootcfg(
    sense=board.GP0,  # column
    source=board.GP8, # row
    midi=False,
    mouse=False,
    storage=False,
    usb_id={'manufacturer': 'KMK Keyboards', 'product': 'Custom 60% Ergo'},
)

```
*Tip*: for a diode direction from rows to columns, switch row and column GPIOs
when assigning them to sense and source.

### Example 2
Dedicated switch to disable boot configuration, connected to ground:

```python
import board

from kmk.bootcfg import bootcfg

bootcfg(sense=board.GP22, ...)
```

### Example 3
Shut-in mode:
**Always** apply boot configuration and disable any contact to the outside
world.
**Caution**: this an example for a `DigitalInOut` sense pin, and probably an
unwise thing to do in actuality.

```python
import board
import digitalio

from kmk.bootcfg import bootcfg

sense = digitalio.DigitalInOut(board.GP42)
sense.direction = digitalio.Direction.OUTPUT
sense = True

bootcfg(
    sense=sense,
    cdc_console=False,
    consumer_control=False,
    keyboard=False,
    midi=False,
    mouse=False,
    storage=False,
)
```

We generally advise against importing your keyboard definition and using
rows/columns to define sense and source pins, because that essentially loads
the firmware twice, almost doubling boot times.

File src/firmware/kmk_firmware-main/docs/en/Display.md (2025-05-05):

# Display
Not enough screen space? Add a display to your keyboard!

This documentation concerns the recommended Display extension.

*Note:*
Driving a display can bind up a considerable amount of CPU time and RAM.
Be aware of the performance degradation that can occur.

## Preparation
First of all you need to download a few libraries that will make it possible for your display to work.
You can get them with the [Adafruit CircuitPython Libraries bundle](https://circuitpython.org/libraries).
Make sure you to choose the one that matches your version of CircuitPython.

Create a `lib` directory under the CircuitPython drive and copy the following
from the library bundle there:
* `adafruit_display_text/`

Depending on which kind of display your keyboard has, you may also need a display-specific library. See the below table:

| Display Type | Library to use |
| --- | --- |
| SSD1306 | `adafruit_displayio_ssd1306.mpy` |
| SH1106 | `adafruit_displayio_sh1106.mpy` |
| Already initialized (e.g. available through `board.DISPLAY`) | None |

## Configuration
Here's how you may initialize the extension. Note that this includes examples of all currently supported display types and you only need the one that corresponds to your display:

```python
import board
import busio

from kmk.extensions.display import Display, TextEntry, ImageEntry

# For SSD1306
from kmk.extensions.display.ssd1306 import SSD1306

# Replace SCL and SDA according to your hardware configuration.
i2c_bus = busio.I2C(board.GP_SCL, board.GP_SDA)

driver = SSD1306(
    # Mandatory:
    i2c=i2c_bus,
    # Optional:
    device_address=0x3C,
)

# For SH1106
from kmk.extensions.display.sh1106 import SH1106

# Replace SCK and MOSI according to your hardware configuration.
spi_bus = busio.SPI(board.GP_SCK, board.GP_MOSI)

# Replace command, chip_select, and reset according to your hardware configuration.
driver = SH1106(
    # Mandatory:
    spi=spi_bus,
    command=board.GP_DC,
    chip_select=board.GP_CS,
    reset=board.GP_RESET,
)

# For displays initialized by CircuitPython by default
# IMPORTANT: breaks if a display backend from kmk.extensions.display is also in use
from kmk.extensions.display.builtin import BuiltInDisplay

# Replace display, sleep_command, and wake_command according to your hardware configuration.
driver = BuiltInDisplay(
    # Mandatory:
    display=board.DISPLAY
    sleep_command=0xAE
    wake_command=0xAF
)

# For all display types
display = Display(
    # Mandatory:
    display=driver,
    # Optional:
    width=128, # screen size
    height=32, # screen size
    flip = False, # flips your display content
    flip_left = False, # flips your display content on left side split
    flip_right = False, # flips your display content on right side split
    brightness=0.8, # initial screen brightness level
    brightness_step=0.1, # used for brightness increase/decrease keycodes
    dim_time=20, # time in seconds to reduce screen brightness
    dim_target=0.1, # set level for brightness decrease
    off_time=60, # time in seconds to turn off screen
    powersave_dim_time=10, # time in seconds to reduce screen brightness
    powersave_dim_target=0.1, # set level for brightness decrease
    powersave_off_time=30, # time in seconds to turn off screen
)
```
Also shown are all the options with their default values.
Customize them to fit your screen and preferences.

## Images
Images have to be monochromatic bitmaps with same resolution as your display and
have to be placed in the root of the CircuitPython drive.
**Placing it in separate a separate directory may cause issues.**

```python
display.entries = [
    ImageEntry(image="1.bmp", x=0, y=0),
]
keyboard.extensions.append(display)
```

You can also make your images appear only on specific layers,

```python
display.entries = [
    ImageEntry(image="1.bmp", x=0, y=0, layer=0),
    ImageEntry(image="2.bmp", x=0, y=0, layer=1),
]
keyboard.extensions.append(display)
```

and/or side of your split keyboard.

```python
display.entries = [
    ImageEntry(image="L1.bmp", x=0, y=0, side="L"),
    ImageEntry(image="R1.bmp", x=0, y=0, side="R"),
]
keyboard.extensions.append(display)
```

## Text
You're able to freely position your text to place it wherever you want just by changing x and y values.

```python
display.entries = [
    TextEntry(text="Layer = 1", x=0, y=0),
    TextEntry(text="Macros", x=0, y=12),
    TextEntry(text="Hey there!", x=0, y=24),
]
keyboard.extensions.append(display)
```

### X and Y anchors
Anchor points define the "origin" or `(0, 0)` position within a text label.
Example: for text in top right corner you need to set its anchor points Top Right and move text to far right position.
The values can be set "T" for top, "M" for middle and "B" for bottom on the X
axis and "L" for left, "M" for middle and "R, for right on the Y axis.

For more info about anchors check the [Adafruit docs](https://learn.adafruit.com/circuitpython-display-support-using-displayio/text).
Notable difference: KMK uses strings ("T", "M","B" and "L", "M", "R") instead of numbers.

```python
display.entries = [
    TextEntry(text="Layer = 1", x=128, y=0, x_anchor="R", y_anchor="T"), # text in Top Right corner
    TextEntry(text="Macros", x=128, y=64, x_anchor="R", y_anchor="B"), # text in Bottom Right corner
    TextEntry(text="Hey there!", x=64, y=32, x_anchor="M", y_anchor="M"), # text in the Middle of screen
]
keyboard.extensions.append(display)
```

### Split
Same as with images you can change displaying according to current layer or side of split keyboard.

```python
display.entries = [
    TextEntry(text="Longer text that", x=0, y=0, layer=0),
    TextEntry(text="has been divided", x=0, y=12, layer=0, side="L"),
    TextEntry(text="for an example", x=0, y=24, layer=0, side="R"),
]
keyboard.extensions.append(display)
```

### Inverting
Inverts colors of your text. Comes in handy, for example, as a good layer indicator.

```python
display = Display(
    entries=[
        TextEntry(text='0 1 2 4', x=0, y=0),
        TextEntry(text='0', x=0, y=0, inverted=True, layer=0),
        TextEntry(text='1', x=12, y=0, inverted=True, layer=1),
        TextEntry(text='2', x=24, y=0, inverted=True, layer=2),
    ],
)
```

# Example Code
```python
import board
import busio
from kmk.kmk_keyboard import KMKKeyboard
from kmk.keys import KC
from kmk.scanners import DiodeOrientation
from kmk.modules.layers import Layers
from kmk.extensions.display import Display, SSD1306, TextEntry, ImageEntry

keyboard = KMKKeyboard()
layers = Layers()
keyboard.modules.append(layers)

i2c_bus = busio.I2C(board.GP21, board.GP20)
display_driver = SSD1306(
    i2c=i2c_bus,
    # Optional device_addres argument. Default is 0x3C.
    # device_address=0x3C,
)

display = Display(
    display=display_driver,
    entries=[
        TextEntry(text='Layer: ', x=0, y=32, y_anchor='B'),
        TextEntry(text='BASE', x=40, y=32, y_anchor='B', layer=0),
        TextEntry(text='NUM', x=40, y=32, y_anchor='B', layer=1),
        TextEntry(text='NAV', x=40, y=32, y_anchor='B', layer=2),
        TextEntry(text='0 1 2', x=0, y=4),
        TextEntry(text='0', x=0, y=4, inverted=True, layer=0),
        TextEntry(text='1', x=12, y=4, inverted=True, layer=1),
        TextEntry(text='2', x=24, y=4, inverted=True, layer=2),
    ],
    # Optional width argument. Default is 128.
    # width=128,
    height=64,
    dim_time=10,
    dim_target=0.2,
    off_time=1200,
    brightness=1,
)

keyboard.extensions.append(display)
```

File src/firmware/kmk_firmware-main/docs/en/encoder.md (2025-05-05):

# Encoder module
Add twist control to your keyboard! Volume, zoom, anything you want.

I2C encoder type has been tested with the Adafruit I2C QT Rotary Encoder with NeoPixel.

**Note:** If you have a **split** keyboard and encoders on **both sides** should work, it's currently necessary to use the encoder-scanner explained at the bottom of [scanners docs](scanners.md).

## Enabling the extension
The constructor(`EncoderHandler` class) takes a list of encoders, each one defined as either:

* a list of `pad_a` pin, `pad_b` pin, `button_pin` and optionally a flag set to `True` if you want encoder direction to be reversed;
* a `busio.I2C`, address and optionally a flag set to `True` if you want it to be reversed.

The `encoder_map` is modeled after the keymap and works the same way. It should have as many layers (key pressed on "turned left", key pressed on "turned right", key pressed on "knob pressed") as your keymap, and use `KC.NO` keys for layers that you don't require any action. The encoder supports a velocity mode if you desire to make something for video or sound editing. 

## How to use
Here is all you need to use this module in your `main.py` / `code.py` file.

1. Load the module: import encoder handler and add it to keyboard modules.

```python
from kmk.modules.encoder import EncoderHandler
encoder_handler = EncoderHandler()
keyboard.modules = [layers, holdtap, encoder_handler]
```

2. Define the pins for each encoder: `pin_a`, `pin_b` for rotations, `pin_button` for the switch in the encoder. Set switch to `None` if the encoder's button is handled differently (as a part of matrix for example) or not at all. If you want to invert the direction of the encoder, set the 4th (optional) parameter `is_inverted` to `True`. 5th parameter is [encoder divisor](#encoder-resolution) (optional), it can be either `2` or `4`. If your encoder button pull direction is not the default of `digitalio.Pull.UP`, you may specify the 6th (optional) parameter `button_pull` as `digitalio.Pull.DOWN`.

```python
# Regular GPIO Encoder
encoder_handler.pins = (
    # regular direction encoder and a button
    (board.GP17, board.GP15, board.GP14,), # encoder #1 
    # reversed direction encoder with no button handling and divisor of 2
    (board.GP3, board.GP5, None, True, 2,), # encoder #2
    )
```

Or in case you have an I2C encoder on a special PCB (e.g. Adafruit I2C QT Rotary Encoder), define I2C encoder as following.

```python
# I2C Encoder

# Setup i2c
SDA = board.GP0
SCL = board.GP1
i2c = busio.I2C(SCL, SDA)

encoder_handler.pins = ((i2c, 0x36, False), (encoder 2 definition), etc. )
```

3. Define the mapping of keys to be called for each layer.

```python
# You can optionally predefine combo keys as for your layout
Zoom_in = KC.LCTRL(KC.EQUAL)
Zoom_out = KC.LCTRL(KC.MINUS)

encoder_handler.map = [ (( KC.VOLD, KC.VOLU, KC.MUTE), (encoder 2 definition), etc. ), # Layer 1
                        ((Zoom_out, Zoom_in, KC.NO), (encoder 2 definition), etc. ), # Layer 2
                        ((KC.A, KC.Z, KC.N1), (encoder 2 definition), etc. ), # Layer 3
                        ((KC.NO, KC.NO, KC.NO), (encoder 2 definition), etc. ), # Layer 4
                      ]
```

## Encoder divisor

Depending on your encoder resolution, it may send 4 or 2 pulses (state changes) on every detent. This number is controlled by the `divisor` property. By default the divisor is set to 4, but if your encoder only activates on every second detent (skips pulses), set the divisor to 2. If the encoder activates twice on every detent, set the value to 4.

You can change the default globally for all encoders **before** initializing the encoder pins (`main.py` file):
```python
encoder_handler.divisor = 2
encoder_handler.pins = ( (board.GP14, board.GP15, None), (board.GP26, board.GP27, None), )
```

Or if you have different types of encoders, set divisor for each encoder individually:
```python
encoder_handler.pins = (
    (board.GP14, board.GP15, None, False, 4), 
    (board.GP26, board.GP27, None, False, 2),
    (board.GP26, board.GP27, None ), # will be set to global default
)
```

This setting is equivalent to `divisor` in the [`rotaryio`](https://docs.circuitpython.org/en/latest/shared-bindings/rotaryio/index.html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) module.
The divisor of `1` for smooth encoders is not currently supported but you can use the divisor of `2` for them without issues and any noticeable difference. 

## Handler methods overrides

Encoder methods `on_move_do` and `on_button_do` can be overridden for complex use cases.

## Connecting the encoder

Most EC11, EC12 and similar encoders have a common pinout shown below. For EVQWGD001 horizontal roller encoder, the pins are ordered `Pin A`, `Pin B`, `Ground`, and the fourth (furthest from the two switch pins) is not connected. This information is provided just for reference — always refer to the manufacturer datasheet for the correct pinout.

```
            +----------+                
 Pin A  ----|          |                
            |          |----- Ground    
 Ground ----|          |                
            |          |----- Switch Pin
 Pin B  ----|          |                
            +----------+                
```

In this configuration the encoder push button has its own dedicated pin. If the button should instead be a part of the matrix, it needs to be wired to Column and Row like other switches instead of ground.

---

## Full example (with 1 encoder)

```python
import board

from kmk.kmk_keyboard import KMKKeyboard
from kmk.consts import UnicodeMode
from kmk.keys import KC
from kmk.scanners import DiodeOrientation
from kmk.modules.layers import Layers
from kmk.modules.encoder import EncoderHandler

keyboard = KMKKeyboard()
layers = Layers()
encoder_handler = EncoderHandler()
keyboard.modules = [layers, encoder_handler]

keyboard.col_pins = (
    board.GP0, board.GP1, board.GP2, board.GP3, board.GP4, board.GP5,
    board.GP6, board.GP7, board.GP8, board.GP9, board.GP10, board.GP11,
    board.GP12, board.GP13,
)
keyboard.row_pins = (board.GP28, board.GP27, board.GP22, board.GP26, board.GP21)
keyboard.diode_orientation = DiodeOrientation.COLUMNS

# I2C example
#import busio
#SDA = board.GP0
#SCL = board.GP1
#i2c = busio.I2C(SCL, SDA)
#encoder_handler.i2c = ((i2c, 0x36, False),)

# encoder_handler.divisor = 2 # for encoders with more precision
encoder_handler.pins = ((board.GP17, board.GP15, board.GP14, False),)

# Filler keys
_______ = KC.TRNS
xxxxxxx = KC.NO
tbdtbd = KC.A

# Layers
LYR_STD, LYR_EXT, LYR_NUM, LYR_GAME = 0, 1, 2, 3

TO_STD = KC.DF(LYR_STD)
MT_EXT = KC.MO(LYR_EXT)
TO_NUM = KC.MO(LYR_NUM)
TO_GAME = KC.DF(LYR_GAME)

# Keymap

keyboard.keymap = [
    # Standard (ISO) Layer
    [
        KC.ESC , KC.N1  , KC.N2  , KC.N3  , KC.N4  , KC.N5  , KC.N6  , KC.N7  , KC.N8  , KC.N9  , KC.N0  , KC.MINS, KC.EQL , KC.BSPC,
        KC.TAB , KC.Q   , KC.W   , KC.E   , KC.R   , KC.T   , KC.Y   , KC.U   , KC.I   , KC.O   , KC.P   , KC.LBRC, KC.RBRC, KC.DEL ,
        xxxxxxx, KC.A   , KC.S   , KC.D   , KC.F   , KC.G   , KC.H   , KC.J   , KC.K   , KC.L   , KC.SCLN, KC.QUOT, KC.NUHS, xxxxxxx,
        KC.LSFT, KC.NUBS, KC.Z   , KC.X   , KC.C   , KC.V   , KC.B   , KC.N   , KC.M   , KC.COMM, KC.DOT , KC.SLSH, KC.UP  , KC.ENT ,
        KC.LCTL, KC.LGUI, xxxxxxx, KC.LALT, MT_EXT , xxxxxxx, KC.SPC , xxxxxxx, KC.RALT, TO_NUM , KC.RSFT, KC.LEFT, KC.DOWN, KC.RGHT,
    ],
    # Extra Keys Layer
    [
        TO_STD , KC.F1  , KC.F2  , KC.F3  , KC.F4  , KC.F5  , KC.F6  , KC.F7  , KC.F8  , KC.F9  , KC.F10 , KC.F11 , KC.F12 , KC.RESET,
        _______, KC.N1  , KC.N2  , KC.N3  , KC.N4  , KC.N5  , KC.N6  , KC.N7  , KC.N8  , KC.N9  , KC.N0  , KC.MINS, KC.EQL , _______,
        xxxxxxx, _______, _______, _______, _______, _______, _______, _______, _______, _______, _______, _______, _______, xxxxxxx,
        KC.LSFT, _______, _______, _______, _______, _______, _______, _______, _______, _______, _______, _______, KC.PGUP, _______,
        KC.LCTL, KC.LGUI, xxxxxxx, KC.LALT, MT_EXT , xxxxxxx, _______, xxxxxxx, _______, TO_NUM , _______, KC.HOME, KC.PGDN, KC.END ,
    ],
    # NumPad Layer
    [
        TO_STD , xxxxxxx, xxxxxxx, xxxxxxx, xxxxxxx, xxxxxxx, xxxxxxx, KC.P7  , KC.P8  , KC.P9  , KC.PSLS, xxxxxxx, xxxxxxx, KC.BSPC,
        xxxxxxx, xxxxxxx, xxxxxxx, xxxxxxx, xxxxxxx, xxxxxxx, xxxxxxx, KC.P4  , KC.P5  , KC.P6  , KC.PAST, xxxxxxx, xxxxxxx, KC.DEL ,
        xxxxxxx, xxxxxxx, xxxxxxx, xxxxxxx, xxxxxxx, xxxxxxx, KC.LPRN, KC.P1  , KC.P2  , KC.P3  , KC.PPLS, xxxxxxx, xxxxxxx, xxxxxxx,
        xxxxxxx, xxxxxxx, xxxxxxx, xxxxxxx, xxxxxxx, xxxxxxx, KC.RPRN, KC.P0  , KC.PDOT, _______, KC.PMNS, xxxxxxx, xxxxxxx, KC.PENT,
        xxxxxxx, xxxxxxx, xxxxxxx, xxxxxxx, MT_EXT , xxxxxxx, xxxxxxx, xxxxxxx, xxxxxxx, TO_NUM , xxxxxxx, xxxxxxx, xxxxxxx, xxxxxxx,
    ],
    # Gaming Layer
    [
        TO_STD , xxxxxxx, xxxxxxx, xxxxxxx, xxxxxxx, xxxxxxx, xxxxxxx, xxxxxxx, xxxxxxx, xxxxxxx, xxxxxxx, xxxxxxx, xxxxxxx, xxxxxxx,
        xxxxxxx, xxxxxxx, xxxxxxx, xxxxxxx, xxxxxxx, xxxxxxx, xxxxxxx, xxxxxxx, xxxxxxx, xxxxxxx, xxxxxxx, xxxxxxx, xxxxxxx, xxxxxxx,
        xxxxxxx, xxxxxxx, xxxxxxx, xxxxxxx, xxxxxxx, xxxxxxx, xxxxxxx, xxxxxxx, xxxxxxx, xxxxxxx, xxxxxxx, xxxxxxx, xxxxxxx, xxxxxxx,
        xxxxxxx, xxxxxxx, xxxxxxx, xxxxxxx, xxxxxxx, xxxxxxx, xxxxxxx, xxxxxxx, xxxxxxx, xxxxxxx, xxxxxxx, xxxxxxx, xxxxxxx, xxxxxxx,
        xxxxxxx, xxxxxxx, xxxxxxx, xxxxxxx, MT_EXT , xxxxxxx, xxxxxxx, xxxxxxx, xxxxxxx, TO_NUM , xxxxxxx, xxxxxxx, xxxxxxx, xxxxxxx,
    ],
]

# Rotary Encoder (1 encoder / 1 definition per layer)
encoder_handler.map = [ ((KC.UP, KC.DOWN, KC.MUTE),), # Standard
                        ((KC.VOLD, KC.VOLU, KC.MUTE),), # Extra
                        ((KC.A, KC.Z, KC.N1),), # NumPad not yet properly configured
                        ((KC.A, KC.Z, KC.N1),), # Gaming not yet properly configured
                        ]

if __name__ == "__main__":
    keyboard.go()
```

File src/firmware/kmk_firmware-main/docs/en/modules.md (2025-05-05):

# Modules
Modules, unlike extensions, change how your keyboard works. These are meant to have
the ability to alter the core code in any way. Unlike extensions, these are not in a
sandbox, and can make massive changes to normal operation.

## Core Modules
These modules are provided in all builds and can be enabled. Currently offered
modules are

- [Combos](combos.md): Adds chords and sequences
- [Layers](layers.md): Adds layer support (Fn key) to allow many more keys to be
put on your keyboard.
- [HoldTap](holdtap.md): Adds support for augmented modifier keys to act as one key
when tapped, and modifier when held.
- [Macros](macros.md): Adds macros.
- [Mouse Keys](mouse_keys.md): Adds mouse keycodes.
- [SpaceMouse Keys](spacemouse_keys.md): Adds SpaceMouse keycodes.
- [Sticky Keys](sticky_keys.md): Adds support for sticky keys.
- [Power](power.md): Power saving features. This is mostly useful when on battery power.
- [Split](split_keyboards.md): Keyboards split in two. Seems ergonomic!
- [SerialACE](serialace.md): [DANGER - _see module README_] Arbitrary Code Execution over the data serial.
- [TapDance](tapdance.md): Different key actions depending on how often it is pressed.
- [Dynamic Sequences](dynamic_sequences.md): Records a sequence of keypresses and plays it back.
- [Mouse Jiggler](mouse_jiggler.md): Periodically moves the mouse cursor to keep the host system awake.

### Require Libraries
These modules can be used without specific hardware, but require additional libraries such as the `Adafruit CircuitPython Bundle`.

 - [MIDI](midi.md): Adds sending MIDI data in the form of keymap entries.

### Peripherals
These modules are for specific hardware and may require additional libraries to function.
- [ADNS9800](adns9800.md): Controlling ADNS9800 optical sensor.
- [Encoder](encoder.md): Handling rotary encoders.
- [Pimoroni trackball](pimoroni_trackball.md): Handling a small I2C trackball made by Pimoroni.
- [AS5013 aka EasyPoint](easypoint.md): Handling a small I2C magnetic position sensor made by AMS.

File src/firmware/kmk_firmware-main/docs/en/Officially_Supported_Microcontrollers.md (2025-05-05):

# Officially supported microcontrollers
While most CircuitPython devices are great for hand wired keyboards, most
keyboards are designed to accept a Pro Micro. The boards listed below either 
are, or can be adapted to that pinout to use common keyboards already on the market.

## nice!nano
Features include
- Pro Micro pinout
- Both USB HID and Bluetooth support
- Can do Bluetooth split keyboards with no wires at all
- Has battery support including charging

Downsides
- $25 USD per microcontroller at most retailers
- Not enough space to run KMK without compiling

### Pre-compiling KMK for nice!nano (or any other microcontroller with limited flash)
As the nice!nano has limited flash memory you'll need to use a [compiled KMK](Getting_Started.md#pre-compiling-kmk-for-faster-boot-times-or-microcontrollers-with-limited-flash).

## ItsyBitsy M4 Express
Features include
- Affordable at $15 USD
- Can run most features of KMK including RGB

Downsides
- Needs to be adapted to work with Pro Micro pinout keyboards. You can find a tutorial and files for such an adapter [in our GitHub repository under /hardware](https://github.com/KMKfw/kmk_firmware/tree/master/hardware)

## RP2040
Features include
- Very affordable
- Very powerful for the price

Downsides
- Little support for keyboard kits

## Adafruit ItsyBitsy nRF52840 Express
Features include
- Both USB HID and Bluetooth support
- More affordable than the nice!nano at only $18

Downsides
- Needs to be adapted to work with Pro Micro pinout keyboards. You can find a tutorial and files for such an adapter [in our GitHub repository under /hardware](https://github.com/KMKfw/kmk_firmware/tree/master/hardware)
- No battery support without addon board like [this one by adafruit](https://www.adafruit.com/product/2124) 

## Other microcontrollers
What you'll need to have at minimum
- CircuitPython
- 256KB of flash storage
- HID over USB and/or Bluetooth.

Please keep in mind that KMK relies on CircuitPython's ability to use Bluetooth Low Energy with any given controller.

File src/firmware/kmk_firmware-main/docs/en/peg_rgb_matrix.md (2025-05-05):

# Peg RGB Matrix

## What you can and cannot do with this extension:

### Can Do

* Set any key's LED to be any color in a syntax very similar to your keymap
* Allows specific keys to be set to OFF
* Allows underglow LEDs to be a different color than per-key LEDs
* Allows modifier keys to be set to a different color than alpha keys
* Full split keyboard support
* Change brightness of LEDs from code or using keycodes

### Cannot Do (currently in progress)

* Adjust color at runtime. Currently the extension requires changes to main.py in order to make changes to your LEDs.
* Animations
* Change LED color based on current layer

## Keycodes

Currently this extension does not support changing LEDs at runtime, as a result there are only three keycodes available to interact with this extension,those are:

* `KC.RGB_TOG`. This keycode simply toggles all your LEDs on and off.
* `KC.RGB_BRI`. This keycode increases the brightness of the LEDs.
* `KC.RGB_BRD`. This keycode decreases the brightness of the LEDs.

## Required Libraries

The following libraries must be frozen in your CircuitPython distribution or in a 'lib' folder at the root of your drive.

* [Adafruit_CircuitPython_NeoPixel](https://github.com/adafruit/Adafruit_CircuitPython_NeoPixel)
* [Download .mpy versions from Adafruit_CircuitPython_Bundle](https://github.com/adafruit/Adafruit_CircuitPython_Bundle/releases/download/20220415/adafruit-circuitpython-bundle-7.x-mpy-20220415.zip)

## Required Changes to main.py and kb.py

In order to use this extension the user must make changes to both their kb.py and main.py files. Below you will find a more comprehensive list of changes required in order to use this extension.

### kb.py

It is possible your chosen board may already have these changes made, if not you will need to make these additions:

The board's kb.py needs 3 fields:

* LED Key Position `led_key_pos`
  * Much like `coord_mapping` this tells the extension where the LEDs are on your board.
* Brightness Limit `brightness_limit`
  * Limits your brightness and may be required in order to stabilize performance.
* Number of LEDs `num_pixels`
  * Used for calculations in order to ensure the LEDs map to the correct keys.

#### Non-split Example:

Below shows a simple non-split example for a board containing 48 LEDs total and 38 keys with per-key LEDs. 
This means we will have 10 underglow LEDs and 38 per-key LEDs.
For our example we will assume (because it is most common) the underglow LEDs are connected before the per-key LEDs.
Starting from 0, indexes 0-9 are all underglow, so our `led_key_pos` array starts at 10, the `led_key_pos` array always starts with the key in the upper left position on the board.
Our example is wired in such a way where the positions layout naturally and each row simply increases by 1 starting at the upper left of the board.
Of course if your board's LEDs are laid out different, your `led_key_pos` will need to match that layout.

Underglow LEDs always appear at the end of the `led_key_pos` array, because the array always starts with per-key LEDs.

```python
    led_key_pos=[
        10,11,12,13,14,15,16,17,18,19,
        20,21,22,23,24,25,26,27,28,29,
        30,31,32,33,34,35,36,37,38,39,
           40,41,42,43,44,45,46,47,
                 5, 6, 7, 8, 9,
                 0, 1, 2, 3, 4
        ]
    brightness_limit = 1.0
    num_pixels = 48
```

#### Split Example:

Below shows a 58 key split keyboard's `led_key_pos` array for a board containing 70 LEDs in total.
The board has 58 keys, meaning we are left with 12 underglow LEDs total.
Since the board is a split and we can assume the LEDs are mirrored, that means each half has 29 per-key LEDs and 6 underglow LEDs.

Let's first focus on the left half of the board.
In this example the underglow LEDs are again connected first, and this half has 6 underglow LEDs.
Starting from position 0 this means 0-5 are underglow LEDs and our per-key lighting starts at 6.
Our example board is wired in such a way where the left half's first per-key LED is position in the upper right corner of that half.
The LEDs then increment towards the right and follow a 'zigzag' pattern until all are accounted for (6-34).  

Examining the other half (the right side) you'll notice the LEDs are connected in a similar way but mirrored.
The right half's LEDs start in the upper left position of the board and increment towards the right, and then follow a 'zigzag' pattern until all are accounted for (41-69).

Underglow LEDs always appear at the end of the `led_key_pos` array, because the array always starts with per-key LEDs.

```python
    led_key_pos =[
        11,10,9 ,8 ,7 ,6 ,       41,42,43,44,45,46,
        12,13,14,15,16,17,       52,51,50,49,48,47,
        23,22,21,20,19,18,       53,54,55,56,57,58,
        24,25,26,27,28,29,30, 65,64,63,62,61,60,59,
                 34,33,32,31, 66,67,68,69,
                 3 ,4 ,5 ,       40,39,38,
                 2 ,1 ,0 ,       35,36,37
                 ]
    brightness_limit = 1.0
    num_pixels = 70

```

### main.py

It is possible your chosen board may already have these changes made, if not you will need to make these additions:

```python
from kmk.extensions.peg_rgb_matrix import Rgb_matrix,Rgb_matrix_data,Color
# ... Other code
rgb = Rgb_matrix(...per key color data)
keyboard.extensions.append(rgb)
```

`Rgb_matrix` extension requires one argument (`Rgb_matrix_data`), although additional arguments can be passed, here are all arguments that can be passed to 

`Rgb_matrix`:

* LED Display `ledDisplay`
  * This is our primary and only required field, this takes a `Rgb_matrix_data` class.
    * `Rgb_matrix_data` only takes two fields:
      * Keys: an array of colors with a length equal to the number of keys on your keyboard
      * Underglow: an array of colors with a length equal to the number of underglow leds on your keyboard
* Split `split`
  * This is an optional boolean and only to be used if the keyboard is a split.
* Right Side `rightSide`
  * This is optional boolean only to be used if the keyboard is split. This signals that this configuration is targeting the right side (off side).
* RGB Order `rgb_order`
  * This is optional and only needs to be set if you are not using a WS2812 based LED.
* Disable Auto Write `disable_auto_write`
  * This is optional and only serves to make all your LEDs turn on at once instead of animate to their on state.

### Colors

Colors are RGB and can be provided in one of two ways.
Colors can be defined as an array of three numbers (0-255) or you can use the `Color` class with its default colors, see example below.

#### Passing RGB Codes

```python
Rgb_matrix_data(
    keys=[[255,55,55],[55,55,55],[55,55,55],[55,55,55],[55,55,55],[55,55,55],"""... rest of colors""" ],                     
    underglow=[[0,0,55],[0,0,55],"""... rest of colors""" ]
             )
```

#### Using `Color` Class

```python
Rgb_matrix_data(
    keys=[Color.RED, Color.GREEN, Color.BLUE, Color.WHITE, Color.YELLOW, Color.ORANGE,"""... rest of colors""" ],                     
    underglow=[Color.PURPLE, Color.TEAL, Color.PINK, Color.OFF,"""... rest of colors""" ]
             )
```

### Full Examples

```python
rgb = Rgb_matrix(ledDisplay=Rgb_matrix_data(
    keys=[
    [255,55,55],[55,55,55],[55,55,55],[55,55,55],[55,55,55],[55,55,55],                        [55,55,55],[55,55,55],[55,55,55],[55,55,55],[55,55,55],[255,55,55],
    [255,55,55],[55,55,55],[55,55,55],[55,55,55],[55,55,55],[55,55,55],                        [55,55,55],[55,55,55],[55,55,55],[55,55,55],[55,55,55],[255,55,55],
    [255,55,55],[55,55,55],[55,55,55],[55,55,55],[55,55,55],[55,55,55],                        [55,55,55],[55,55,55],[55,55,55],[55,55,55],[55,55,55],[255,55,55],
    [255,55,55],[55,55,55],[55,55,55],[55,55,55],[55,55,55],[55,55,55],[255,55,55],[255,55,55],[55,55,55],[55,55,55],[55,55,55],[55,55,55],[55,55,55],[255,55,55],
                                     [255,55,55],[55,55,55],[55,55,55],[255,55,55],[255,55,55],[55,55,55],[55,55,55],[255,55,55]],
                                    
    underglow=[ 
             [0,0,55],[0,0,55],[0,0,55],[0,0,55],[0,0,55],[0,0,55],[0,0,55],[0,0,55],[0,0,55],[0,0,55],[0,0,55],[0,0,55]]
             ),
    split=True,
    rightSide=True,
    disable_auto_write=True)
```

#### Bonus

Because creating `ledDisplay` can be time consuming, there is a utility available that will generate a basic framework for you.

```python
Rgb_matrix_data.generate_led_map(58,10,Color.WHITE,Color.BLUE)
```

Call `Rgb_matrix_data.generate_led_map` before you do any configuration beyond imports and it will print an `Rgb_matrix_data` class to your CircuitPython REPL which you can view by using a tool like "screen" or "PUTTY".

Generate LED Map Arguments:

* Number of Keys
* Number of Underglow
* Key Color
* Underglow Color

Example Using Above Arguments:

```python
Rgb_matrix_data(keys=[[249, 249, 249], [249, 249, 249], [249, 249, 249], [249, 249, 249], [249, 249, 249], [249, 249, 249], [249, 249, 249], [249, 249, 249], [249, 249, 249], [249, 249, 249], [249, 249, 249], [249, 249, 249], [249, 249, 249], [249, 249, 249], [249, 249, 249], [249, 249, 249], [249, 249, 249], [249, 249, 249], [249, 249, 249], [249, 249, 249], [249, 249, 249], [249, 249, 249], [249, 249, 249], [249, 249, 249], [249, 249, 249], [249, 249, 249], [249, 249, 249], [249, 249, 249], [249, 249, 249], [249, 249, 249], [249, 249, 249], [249, 249, 249], [249, 249, 249], [249, 249, 249], [249, 249, 249], [249, 249, 249], [249, 249, 249], [249, 249, 249], [249, 249, 249], [249, 249, 249], [249, 249, 249], [249, 249, 249], [249, 249, 249], [249, 249, 249], [249, 249, 249], [249, 249, 249], [249, 249, 249], [249, 249, 249], [249, 249, 249], [249, 249, 249], [249, 249, 249], [249, 249, 249], [249, 249, 249], [249, 249, 249], [249, 249, 249], [249, 249, 249], [249, 249, 249], [249, 249, 249]],
underglow=[[0, 0, 255], [0, 0, 255], [0, 0, 255], [0, 0, 255], [0, 0, 255], [0, 0, 255], [0, 0, 255], [0, 0, 255], [0, 0, 255], [0, 0, 255]])
```

[Connecting to the Serial Console](https://learn.adafruit.com/welcome-to-circuitpython/kattni-connecting-to-the-serial-console)

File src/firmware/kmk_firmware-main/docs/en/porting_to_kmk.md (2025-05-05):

# Porting to KMK 
Porting a board to KMK is quite simple, and follows this base format.

```python
import board

from kmk.kmk_keyboard import KMKKeyboard as _KMKKeyboard
from kmk.scanners import DiodeOrientation
{EXTENSIONS_IMPORT}

class KMKKeyboard(_KMKKeyboard):
{REQUIRED}
    extensions = []

```

## REQUIRED
This is designed to be replaced with the defining pins of your keyboard. Rows, 
columns and the diode direction (if any), should be defined like this
```python
    row_pins = [board.p0_31, board.p0_29, board.p0_02, board.p1_15]
    col_pins = [board.p0_22, board.p0_24, board.p1_00, board.p0_11, board.p1_04]
    diode_orientation = DiodeOrientation.COL2ROW
```

## Additional pins for extensions
KMK includes built in extensions for RGB and split keyboards, and powersave. If
these are applicable on your keyboard/microcontroller, the pins should be added
here. Refer to the instructions on the respective extensions page on how to add 
them. If not adding any extensions, leave this as an empty list as shown.

# Coord mapping
If your keyboard is not built electrically as a square (though most are), you can
provide a mapping directly. An example of this is the 
[Corne](https://github.com/foostan/crkbd). That has 12 columns for 3 rows, and 6 
columns for the bottom row. Split keyboards count as the total keyboard, not per 
side, the right side being offset by the number of keys on the left side, as if
the rows were stacked.
That would look like this:
```python
coord_mapping = [
 0,  1,  2,  3,  4,  5,  24, 25, 26, 27, 28, 29,
 6,  7,  8,  9, 10, 11,  30, 31, 32, 33, 34, 35,
12, 13, 14, 15, 16, 17,  36, 37, 38, 39, 40, 41,
            21, 22, 23,  42, 43, 44,
]
```

Note: Not all numbers are necessarily used ! The keyboard assumes
`number of line * number of rows` keys. Some of the possible keys might not be
used. For example a keyboard with 60 keys might have 8 rows, 8 cols, allowing
64 total combinations -- hence 64 keys. 4 numbers will then not be used for keys
in the `coord_mapping` (might be anyone of them depending of the wiring).

### Find your `coord_mapping`
The following code will help you setup your `coord_mapping` by having every key
send its corresponding number. Use it after your pins and module definition
to define both `keyboard.coord_mapping` and `keyboard.keymap`.

```python
from kmk.modules.macros import Macros
from kmk.keys import KC

keyboard.modules.append(Macros())

# *2 for split keyboards, which will typically manage twice the number of keys
# of one side. Having this N too large will have no impact (maybe slower boot..)
N = len(keyboard.col_pins) * len(keyboard.row_pins) * 2

keyboard.coord_mapping = list(range(N))

layer = []

for i in range(N):
    c, r = divmod(i, 100)
    d, u = divmod(r, 10)
    layer.append(
        KC.MACRO(
            getattr(KC, 'N' + str(c)),
            getattr(KC, 'N' + str(d)),
            getattr(KC, 'N' + str(u)),
            KC.SPC,
        )
    )
keyboard.keymap = [layer]

if __name__ == '__main__':
    keyboard.go()
```

## Keymaps
Keymaps are organized as a list of lists. Keycodes are added for every key on 
each layer. See [keycodes](keycodes.md) for more details on what keycodes are 
available. If using layers or other extensions, also refer to the extensions 
page for additional keycodes.
```python
from kb import KMKKeyboard
from kmk.keys import KC

keyboard = KMKKeyboard()

keyboard.keymap = [
    [KC.A, KC.B],
    [KC.C, KC.D],
]

if __name__ == '__main__':
    keyboard.go()
```

## More information
More information on keymaps can be found in the [config and keymap](config_and_keymap.md) documentation.

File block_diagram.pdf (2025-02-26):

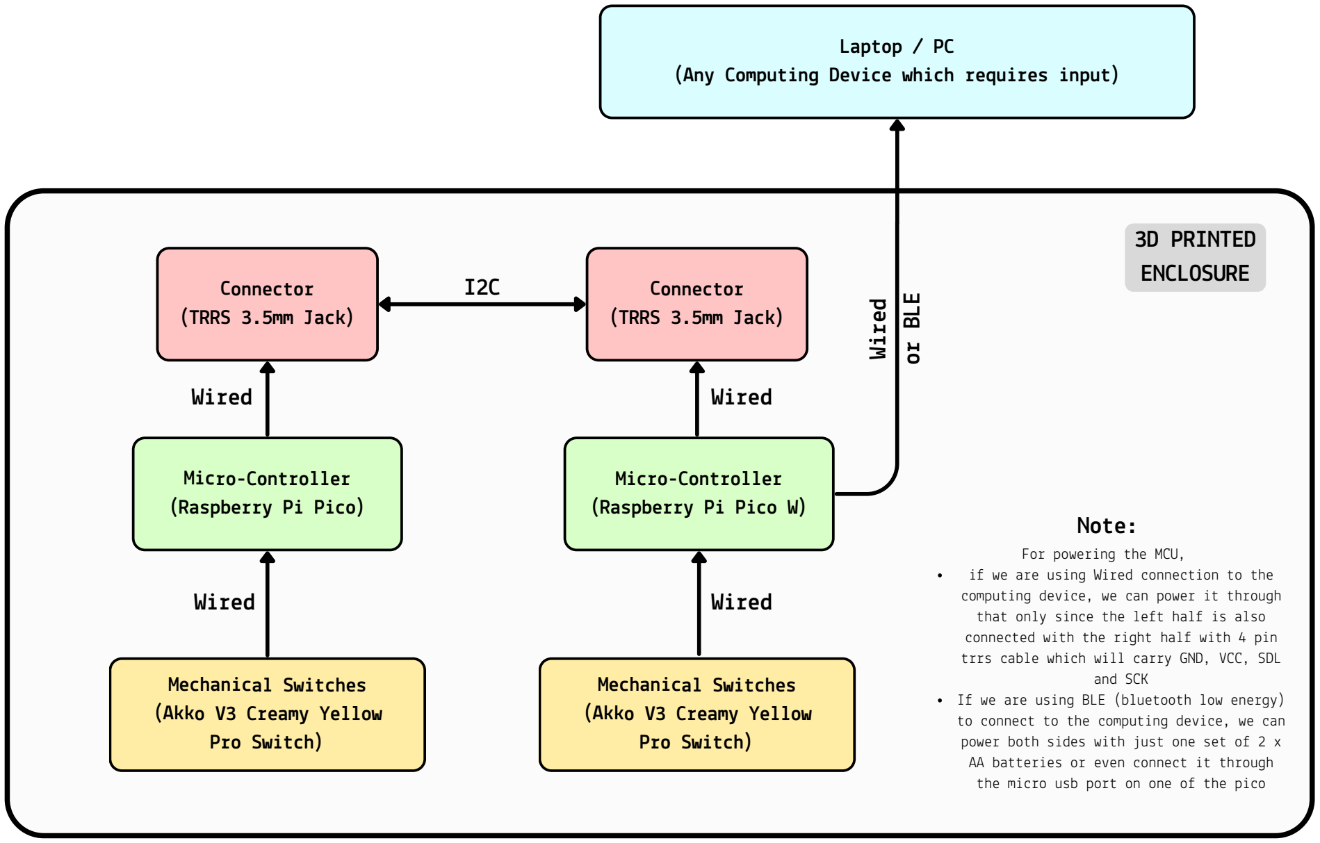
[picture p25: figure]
Micro-Controller (Raspberry Pi Pico W); Micro-Controller (Raspberry Pi Pico); Mechanical Switches (Akko V3 Creamy Yellow Pro Switch); Laptop / PC; Connector (TRRS 3.5mm Jack); Wired; 3D PRINTED ENCLOSURE; Note:; For powering the MCU, if we are using Wired connection to the; that only since the left half is also; and SCK; AA batteries or even connect it through the micro usb port on one of the pico

## (Any Computing Device which requires input)

computing device, we can power it through

connected with the right half with 4 pin trrs cable which will carry GND, VCC, SDL

If we are using BLE (bluetooth low energy) to connect to the computing device, we can power both sides with just one set of 2 x

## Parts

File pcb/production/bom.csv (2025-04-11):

Designator | Footprint | Quantity | Value | LCSC Part #
S1, S10, S11, S12, S13, S14, S15, S16, S17, S18, S2, S3, S4, S5, S6, S7, S8, S9 | SW_MX_reversible | 18 | Keyswitch
U1 | Raspberry_Pi_Pico | 1 | Raspberry_Pi_Pico
U2, U3 | TRRS-PJ-320D | 2 | TRRS

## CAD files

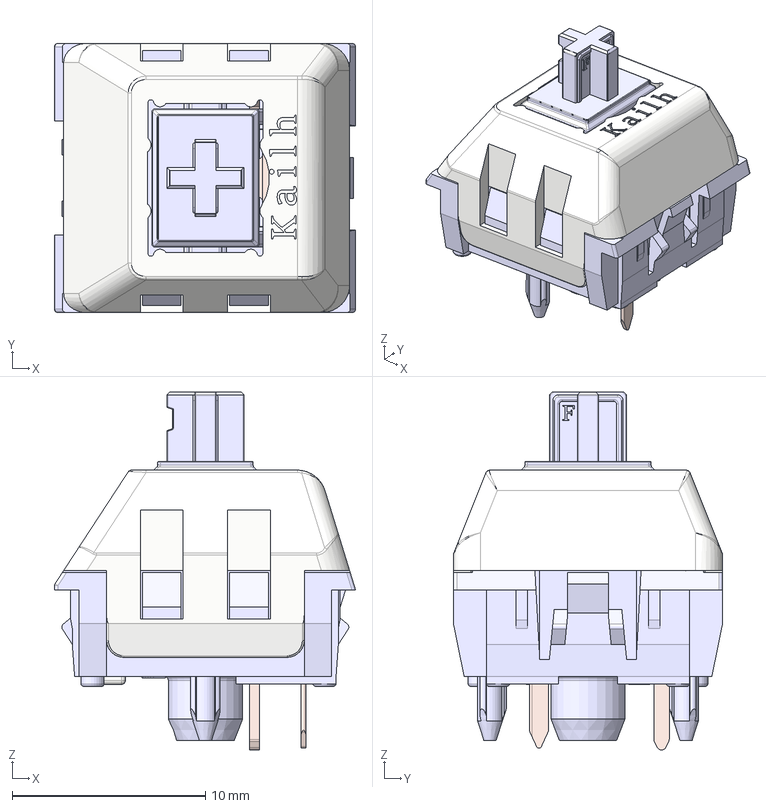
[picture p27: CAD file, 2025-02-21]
case/Kailh Polia.step
15.6 x 14.0 x 18.5 mm
Housing
ThickContact
SpringContact
Stem
Lid

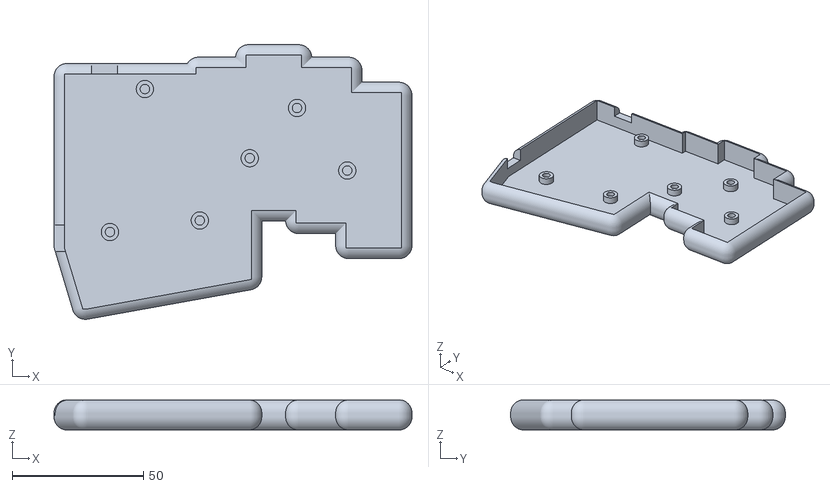
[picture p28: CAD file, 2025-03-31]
case/single_case/right_case.stl
136.2 x 104.5 x 11.4

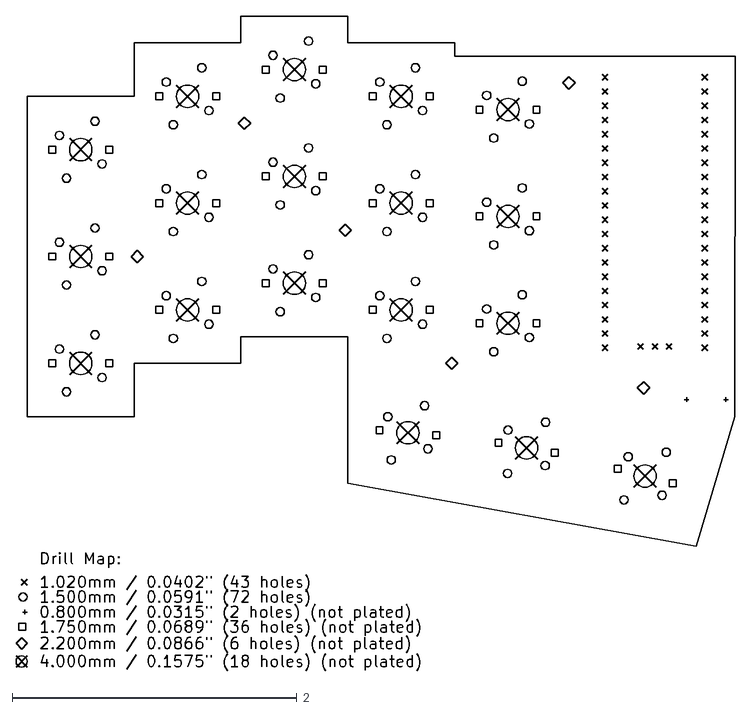
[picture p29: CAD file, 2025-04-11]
pcb/split-drl_map.dxf
5.05 x 4.60

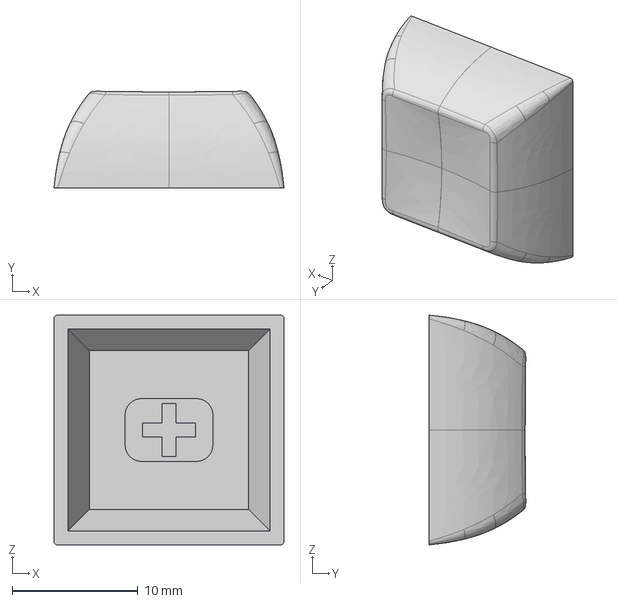
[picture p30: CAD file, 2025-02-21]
case/DSA_Keycap_CherryMX.step
18.3 x 7.69 x 18.3 mm

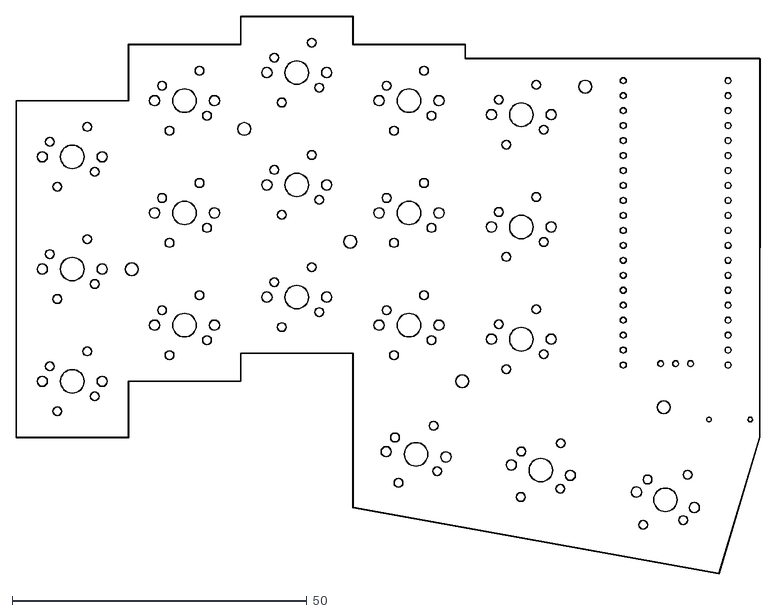
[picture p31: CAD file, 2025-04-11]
pcb/split-Edge_Cuts.dxf
126.3 x 94.6

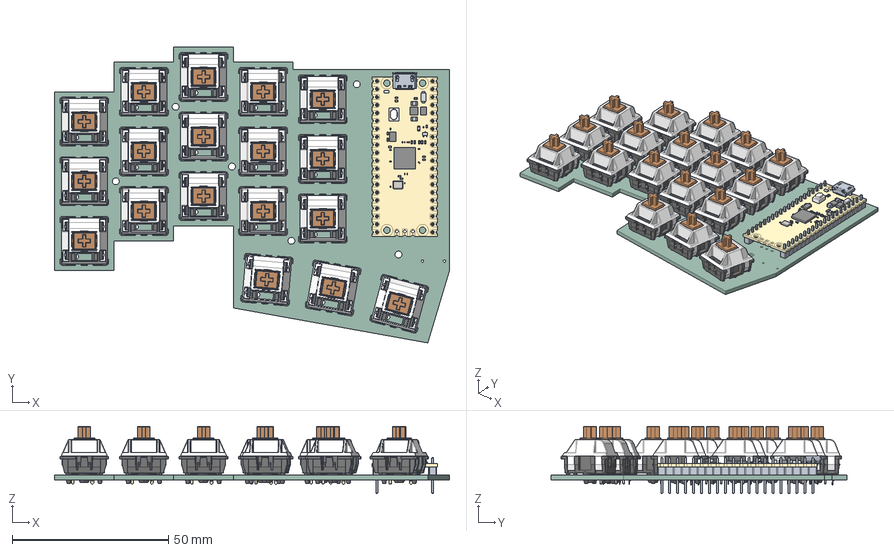
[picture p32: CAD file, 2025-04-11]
pcb/split.step
126.2 x 94.5 x 21.4 mm
SW_Cherry_MX_PCB_cp x 18
root
split_PCB

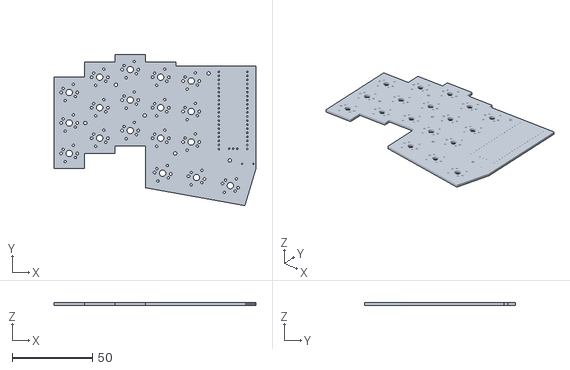
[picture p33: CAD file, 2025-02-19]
case/mesh_bottom.stl
126.2 x 94.5 x 1.60

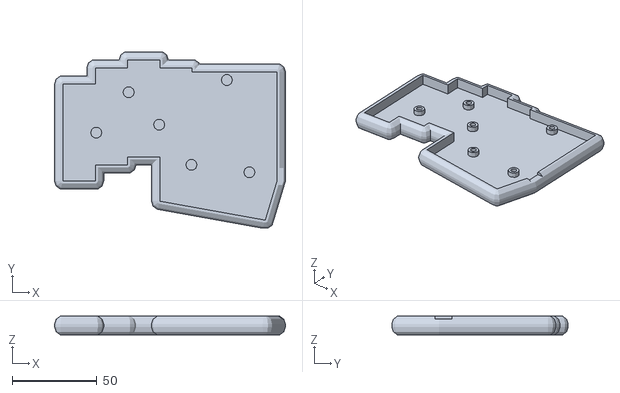
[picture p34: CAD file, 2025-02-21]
case/single_case/case_low_poly.stl
136.2 x 104.0 x 11.0

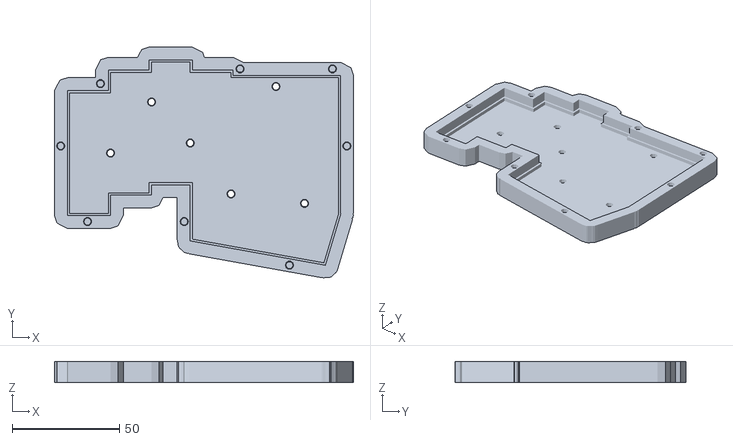
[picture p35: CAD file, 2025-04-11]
pcb/case2.stl
139.2 x 107.5 x 10.0

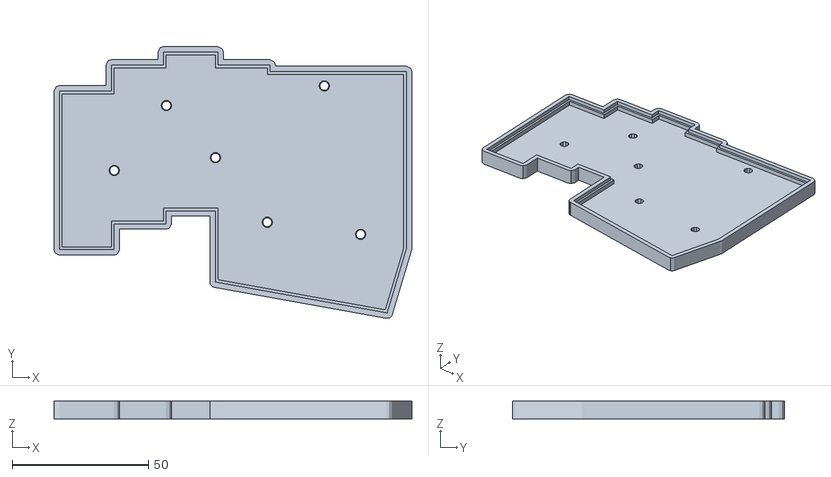
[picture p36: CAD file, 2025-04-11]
pcb/case.stl
131.2 x 99.6 x 6.50

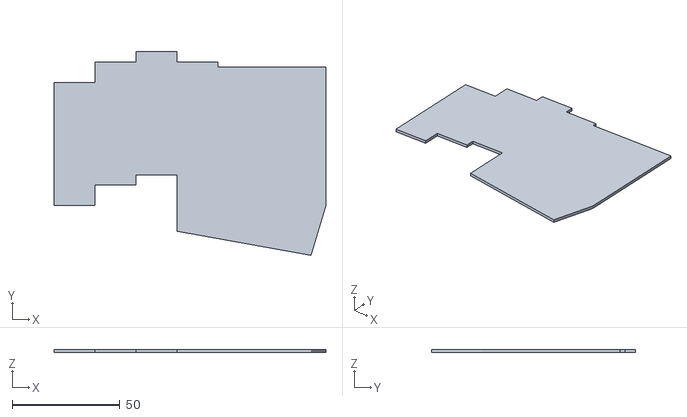
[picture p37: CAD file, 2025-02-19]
case/pcb_without_holes.stl
126.2 x 94.5 x 1.50

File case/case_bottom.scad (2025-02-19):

projection()
difference(){
    minkowski(){
        linear_extrude(1.4)
            projection()
            import("pcb_without_holes.stl");
        cylinder(r=5, h=0.1);
    }
    difference(){
        import("pcb_without_holes.stl");
        import("pcb_with_mounting_holes.stl");
    };
};

/* difference(){ */
/*     translate([10, -120, 0]) */
/*     cube([140, 105, 1.5]); */
    
/*     translate([-80, 20, 0]) */
/*     import("mesh_bottom.stl"); */
/* } */

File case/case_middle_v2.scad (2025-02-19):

SCREW_R = 1.1;


module something(){

    difference(){
        minkowski(){
            linear_extrude(1.4)
                projection()
                import("pcb_without_holes.stl");
            cylinder(r=5, h=0.1);
        }
        import("pcb_without_holes.stl");

        translate([15,-38,0])
            cylinder(h=1.5,r=SCREW_R);
        translate([15,-89,0])
            cylinder(h=1.5,r=SCREW_R);
    }
}

render()
something();

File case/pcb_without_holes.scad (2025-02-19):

/* difference(){ */
/*     translate([10, -120, 0]) */
/*     cube([140, 105, 1.5]); */
    
/*     translate([-80, 20, 0]) */
/*     import("mesh_bottom.stl"); */
/* } */

// required for perfect size but its laggy
/* linear_extrude(1.5){ */
/*     projection(){ */
        union(){
            keyswitch_holes();
            pico_holes();
            /* mounting_holes(); */
            trrs_holes();
            translate([-80, 20, 0])
            import("mesh_bottom.stl");
        }
    /* } */
/* } */

module keyswitch_holes() {
    translate([20,-52,0])
        cube([14,14,1.6]);
    translate([20,-71,0])
        cube([14,14,1.6]);
    translate([20,-90,0])
        cube([14,14,1.6]);

    translate([39,-42,0])
        cube([14,14,1.6]);
    translate([39,-61,0])
        cube([14,14,1.6]);
    translate([39,-80,0])
        cube([14,14,1.6]);

    translate([58,-38,0])
        cube([14,14,1.6]);
    translate([58,-57,0])
        cube([14,14,1.6]);
    translate([58,-76,0])
        cube([14,14,1.6]);

    translate([77,-42,0])
        cube([14,14,1.6]);
    translate([77,-61,0])
        cube([14,14,1.6]);
    translate([77,-80,0])
        cube([14,14,1.6]);
    translate([78,-102,0])
        cube([14,14,1.6]);

    translate([96,-44,0])
        cube([14,14,1.6]);
    translate([96,-63,0])
        cube([14,14,1.6]);
    translate([96,-82,0])
        cube([14,14,1.6]);
    translate([99,-105,0])
        cube([14,14,1.6]);

    translate([121,-110,0])
        cube([14,14,1.6]);
}
module pico_holes() {
    translate([119,-81,0]){
        cube([3, 51, 1.6]);
    }
    translate([137,-81,0]){
        cube([3, 51, 1.6]);
    }
    translate([126,-81,0]){
        cube([8, 3, 1.6]);
    }
}
module mounting_holes(){
    linear_extrude(1.6){
        translate([114,-33,0])
            circle(r=3);
        translate([127,-87,0])
            circle(r=3);
        translate([93,-83,0])
            circle(r=3);
        translate([74,-59,0])
            circle(r=3);
        translate([56,-40,0])
            circle(r=3);
        translate([37,-64,0])
            circle(r=3);
    }
}
module trrs_holes(){
    linear_extrude(1.6){
        translate([135,-89,0])
            circle(r=1);
        translate([142,-89,0])
            circle(r=1);
    }
}

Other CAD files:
case/single_case/case_1mm_tolerance.stl
case/dsa.stl
case/single_case/case_cheap.stl
case/pcb_with_mounting_holes.stl
case/single_case/case.stl
pcb/split36.FCStd
case/first_try_case.FCStd
pcb/case.scad
case/case_middle.scad
case/kicad.step
case/single_case/case.scad
case/single_case/right_case.scad
pcb/pcb.dxf
pcb/split-B_Cu.dxf
pcb/split-B_Mask.dxf
pcb/split-B_Paste.dxf
pcb/split-B_Silkscreen.dxf
pcb/split-F_Cu.dxf
pcb/split-F_Mask.dxf
pcb/split-F_Paste.dxf
pcb/split-F_Silkscreen.dxf

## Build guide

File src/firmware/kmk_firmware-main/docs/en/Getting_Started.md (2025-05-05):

# Getting Started
> Life was like a box of chocolates. You never know what you're gonna get.

KMK is a keyboard focused layer that sits on top of [CircuitPython](https://circuitpython.org/). As such, it should work with most [boards that support CircuitPython](https://circuitpython.org/downloads). KMK requires CircuitPython version 7.3 or above.
Known working and recommended devices can be found in the [list of officially supported microcontrollers](Officially_Supported_Microcontrollers.md)

## TL;DR Quick start guide
> To infinity and beyond!
1. [Install CircuitPython version 7.3 or higher on your board](https://learn.adafruit.com/welcome-to-circuitpython/installing-circuitpython). With most boards, it should be as easy as drag and dropping the firmware on the drive
2. Get an up to date [copy of KMK](https://github.com/KMKfw/kmk_firmware/archive/refs/heads/main.zip) from the main branch 
3. Unzip it and copy the KMK folder and the boot.py file at the root of the USB drive corresponding to your board (often appearing as CIRCUITPY)
4. Create a new *code.py* or *main.py* file in the same root directory (same level as boot.py) with the example content hereunder: 

***IMPORTANT:*** adapt the GP0 / GP1 pins to your specific board !

```
print("Starting")

import board

from kmk.kmk_keyboard import KMKKeyboard
from kmk.keys import KC
from kmk.scanners import DiodeOrientation

keyboard = KMKKeyboard()

keyboard.col_pins = (board.GP0,)
keyboard.row_pins = (board.GP1,)
keyboard.diode_orientation = DiodeOrientation.COL2ROW

keyboard.keymap = [
    [KC.A,]
]

if __name__ == '__main__':
    keyboard.go()
```

5. With a wire / paperclip / whatever, connect the pins you selected for col_pin and row_pin together.

feather and keeboar example pins


6. If it prints the letter "a" (or a "Q" or ... depending on your keyboard layout), you're done!

## Now that you're up and running, you may want to go further...
> This is your last chance. After this, there is no turning back. You take the blue pill—the story ends, you wake up in your bed and believe whatever you want to believe. You take the red pill—you stay in Wonderland, and I show you how deep the rabbit hole goes. Remember: all I'm offering is the truth. Nothing more.

### You're extremely lucky and you have a fully supported keyboard
If your keyboard and microcontroller are officially supported, simply visit the page for your files, and dropping them on the root of the "flash drive".
Those pages can be found in the repositories [boards folder](https://github.com/KMKfw/kmk_firmware/tree/master/boards).
You will need the `kb.py` and `main.py`. If you need more detailed instructions on how to customize the configuration settings and key mappings, please refer to the [config and keymap](config_and_keymap.md) documentation.

### You've got another, maybe DIY, board and want to customize KMK for it  
First, be sure to understand how your device work, and particularly its specific matrix configuration. You can have a look at [how key matrices work](http://pcbheaven.com/wikipages/How_Key_Matrices_Works/) or read the [guide](https://docs.qmk.fm/#/hand_wire) provided by the QMK team for handwired keyboards
Once you've got the gist of it:
- To start customizing your `code.py`/`main.py` file, please refer to the [config and keymap](config_and_keymap.md) and [keys](keys.md) files respectively, which provide detailed instructions on how to modify the configuration settings and key mappings.
- There's a [reference](keycodes.md) of the available keycodes
- [International](international.md) extension adds keys for non US layouts and [Media Keys](media_keys.md) adds keys for ... media

And to go even further:
- [Macros](macros.md) are used for sending multiple keystrokes in a single action
- [Layers](layers.md) can transform the whole way your keyboard is behaving with a single touch
- [HoldTap](holdtap.md) allow you to customize the way a key behaves whether it is tapped or hold, and [TapDance](tapdance.md) depending on the number of times it is pressed

Want to have fun features such as RGB, split keyboards and more? Check out what builtin [modules](modules.md) and [extensions](extensions.md) can do!
You can also get ideas from the various [user examples](https://github.com/KMKfw/kmk_firmware/tree/master/user_keymaps) that we provide and dig into our [documentation](README.md).

### Pre-compiling KMK for faster boot times or microcontrollers with limited flash

There are two options:
1. To compile KMK yourself you'll need to download and install the [compatible mpy-cross](https://adafruit-circuit-python.s3.amazonaws.com/index.html?prefix=bin/mpy-cross/)
  for your Operating System. Don't forget to add it to your PATH, test by running `mpy-cross` from a shell (Powershell, Bash, Fish, etc). Once that's set up, run either `make compile` (if you have `make`) or `python util/compile.py`to generate the `.mpy` versions of KMK files. Then copy the whole compiled `kmk/` directory to your keyboard.

There are even more compile and copy make targets.
Power user can compile KMK and additional libraries, and then load the bytecode and keyboard code
onto a keyboard in one go:
```sh
make compile copy-compiled copy-board MPY_SOURCES='kmk/ lib/' BOARD='boards/someboard' MOUNTPOINT='/media/user/someboard'
```

2. To download a pre-compiled KMK go to [Actions > Build on the KMK GitHub project page](https://github.com/KMKfw/kmk_firmware/actions/workflows/compile.yml),
  click on the latest build, and you'll find the download link at the bottom of the page under Artifacts. Unzip the download and place the contents in the `kmk/` directory on your keyboard.

On certain microcontrollers that will still not be enough of a size reduction to
fit all of KMK onto the flash (nice!nano for example).
You can remove any optional parts of KMK you aren't using.
Start by skipping `kmk/extensions`, `kmk/modules`, and `kmk/quickpin` and adding in only the files under those paths used in your keyboard (i.e. files that are imported in your `main.py` or `kb.py`).

## Additional help and support
> Roads? Where we're going we don't need roads.

In case you need it, debugging help can be found on the [debugging](debugging.md) page.

For asynchronous support and chatter about KMK, [join our Zulip
community](https://kmkfw.zulipchat.com)!

If you ask for help in chat or open a bug report, if possible
make sure your copy of KMK is up-to-date.
In particular, swing by the Zulip chat *before* opening a GitHub Issue about
configuration, documentation, etc. concerns.

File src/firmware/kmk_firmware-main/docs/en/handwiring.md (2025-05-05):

# Handwire keyboards
This guide will not talk about the physical wiring. Check out our 
[recommended microcontrollers](Officially_Supported_Microcontrollers.md) and 
follow this amazing [hand wiring guide](https://docs.qmk.fm/#/hand_wire). That 
guide can be followed until you are setting up the firmware. After wiring the 
keyboard, you can refer to our [porting guide](porting_to_kmk.md)

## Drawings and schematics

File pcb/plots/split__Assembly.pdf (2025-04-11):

3V3 GP9 GP7 | GP26 VSYS GP14 | GP28 GP3 | ADC_VREF GP12 | GP16 GP22 GND GP0 GP13 | GND GND GP18 RUN GND GP10
3V3_EN GP27 VBUS GP8 | GP20 SWDIO

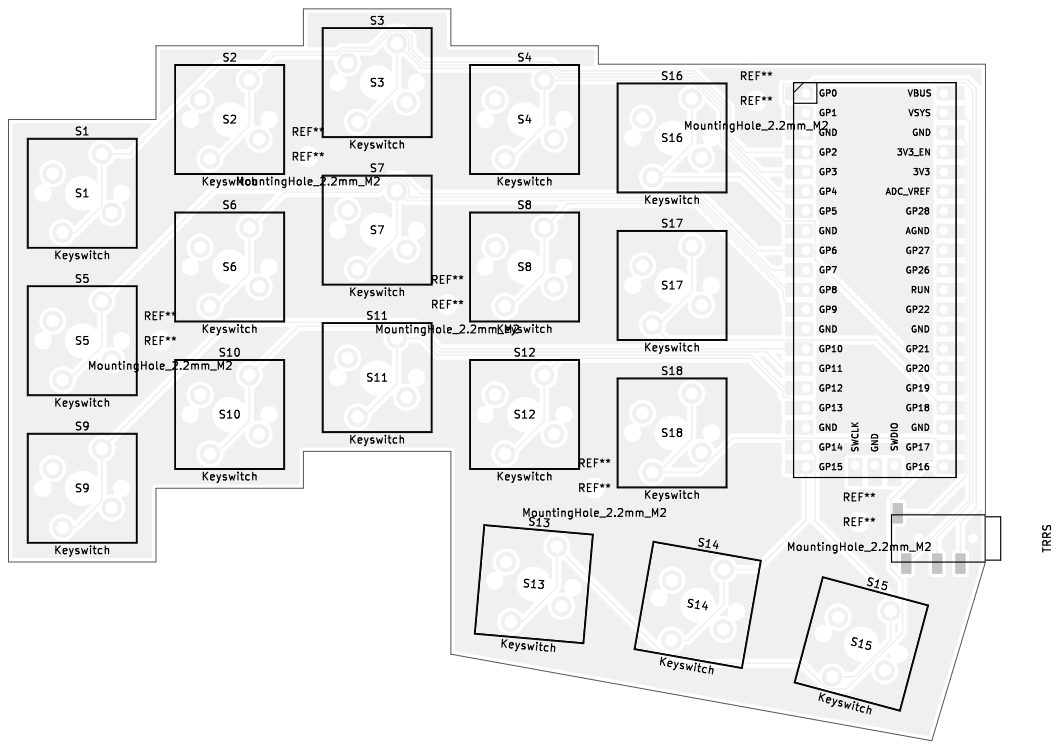
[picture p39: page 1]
SWCLK GND S10; D Date: KiCad; E.D.A. 8.0.7 Size: A4; Rev:; Id: 1/1 Title: File: split.kicad_pcb Sheet: Black; And; White; TOP; Board2Pdf:; Black; TOP -; Page; MountingHole_2.2mm_M2 REF**; Keyswitch S7 Keyswitch S6; MountingHole_2.2mm_M2 REF** Keyswitch S11; MountingHole_2.2mm_M2 REF** Keyswitch S5; Keyswitch S2 Keyswitch S9; Keyswitch S17 MountingHole_2.2mm_M2 REF**; MountingHole_2.2mm_M2 REF** Keyswitch S10; Keyswitch S8

S13 S1 S14 S4 S16 S12 S15 S18 REF** S3 REF** S7 S6 REF** S11 REF** S5 S2 S9 S17 REF** REF** GP19 GP1 GP21 GP2 GP17 GND

S15 Keyswitch S18 MountingHole_2.2mm_M2 REF** Keyswitch S3 TRRS

Keyswitch S13 Keyswitch S1 Keyswitch S14 Keyswitch S4 Keyswitch S16 Keyswitch S12 Keyswitch

AGND GND GND GP15

GP6 GP15 VBUS | SWCLK
3V3_EN | GP11 GP18 | GP4 GP0 GP5 VSYS GP16 | GP8 GP21 SWDIO

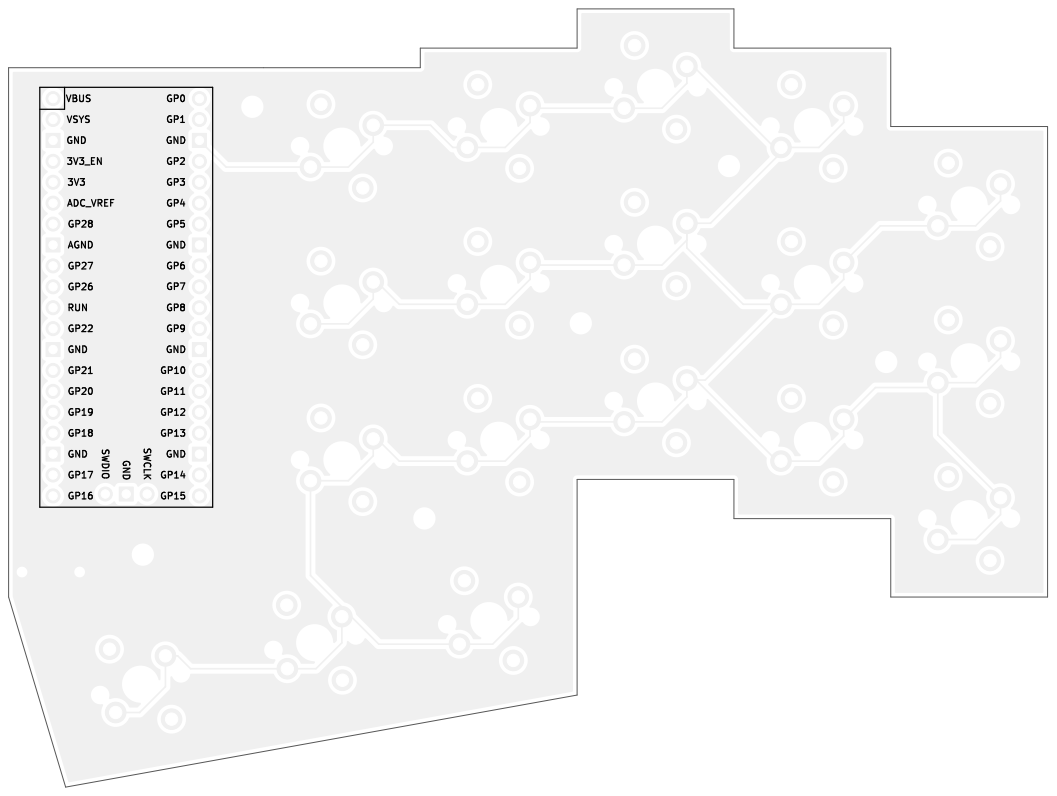
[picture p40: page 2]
AGND GP19 GP26; GP7 GND; GP13 GND GND; RUN; GND GP22; GND; GND GP10; GP12 GND GP28; GP2 GP9 GND; ADC_VREF 1; D Date: KiCad; E.D.A. 8.0.7 Size: A4; Rev:; Id: 1/1 Title: File: split.kicad_pcb Sheet: Black; And; White; BOT Board2Pdf:; Black; BOT -; Page 2/2

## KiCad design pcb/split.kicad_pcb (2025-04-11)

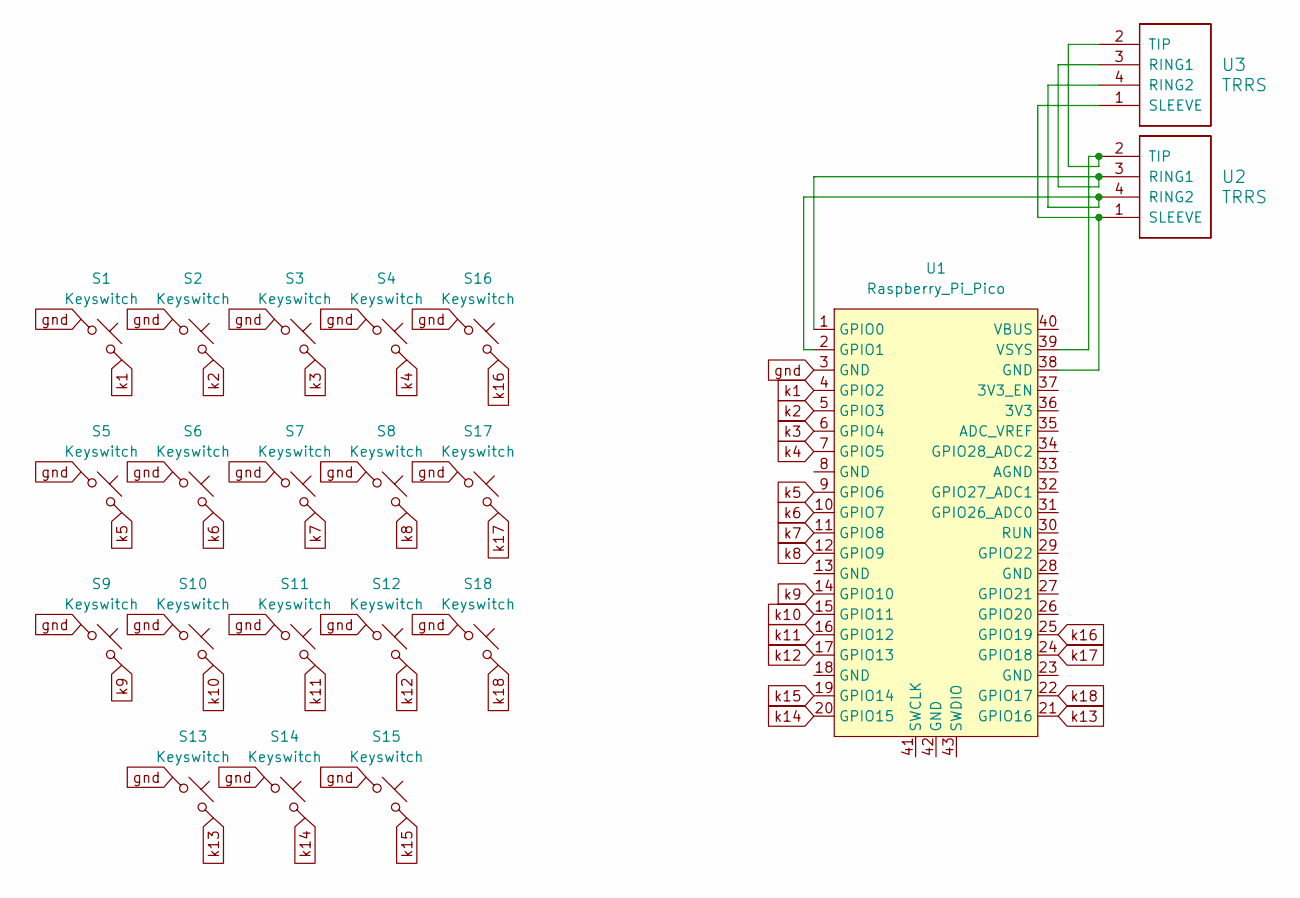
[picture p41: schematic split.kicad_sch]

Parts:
S1, S2, S3, S4, S5, S6, S7, S8, S9, S10, S11, S12, S13, S14, S15, S16, S17, S18: Keyswitch; SW_MX_reversible
U1: Raspberry_Pi_Pico
U2, U3: TRRS; TRRS-PJ-320D

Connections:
unnamed: U1.1 (GPIO0), U2.3 (RING1), U3.3 (RING1)
unnamed: U1.2 (GPIO1), U2.4 (RING2), U3.4 (RING2)
unnamed: U1.39 (VSYS), U2.2 (TIP), U3.2 (TIP)
unnamed: U1.38 (GND), U2.1 (SLEEVE), U3.1 (SLEEVE)
gnd: S1.1, S2.1, S3.1, S4.1, S5.1, S6.1, S7.1, S8.1, S9.1, S10.1, S11.1, S12.1, S13.1, S14.1, S15.1, S16.1, S17.1, S18.1, U1.3 (GND)
k1: S1.2, U1.4 (GPIO2)
k2: S2.2, U1.5 (GPIO3)
k3: S3.2, U1.6 (GPIO4)
k4: S4.2, U1.7 (GPIO5)
k5: S5.2, U1.9 (GPIO6)
k6: S6.2, U1.10 (GPIO7)
k7: S7.2, U1.11 (GPIO8)
k8: S8.2, U1.12 (GPIO9)
k9: S9.2, U1.14 (GPIO10)
k10: S10.2, U1.15 (GPIO11)
k11: S11.2, U1.16 (GPIO12)
k12: S12.2, U1.17 (GPIO13)
k13: S13.2, U1.21 (GPIO16)
k14: S14.2, U1.20 (GPIO15)
k15: S15.2, U1.19 (GPIO14)
k16: S16.2, U1.25 (GPIO19)
k17: S17.2, U1.24 (GPIO18)
k18: S18.2, U1.22 (GPIO17)

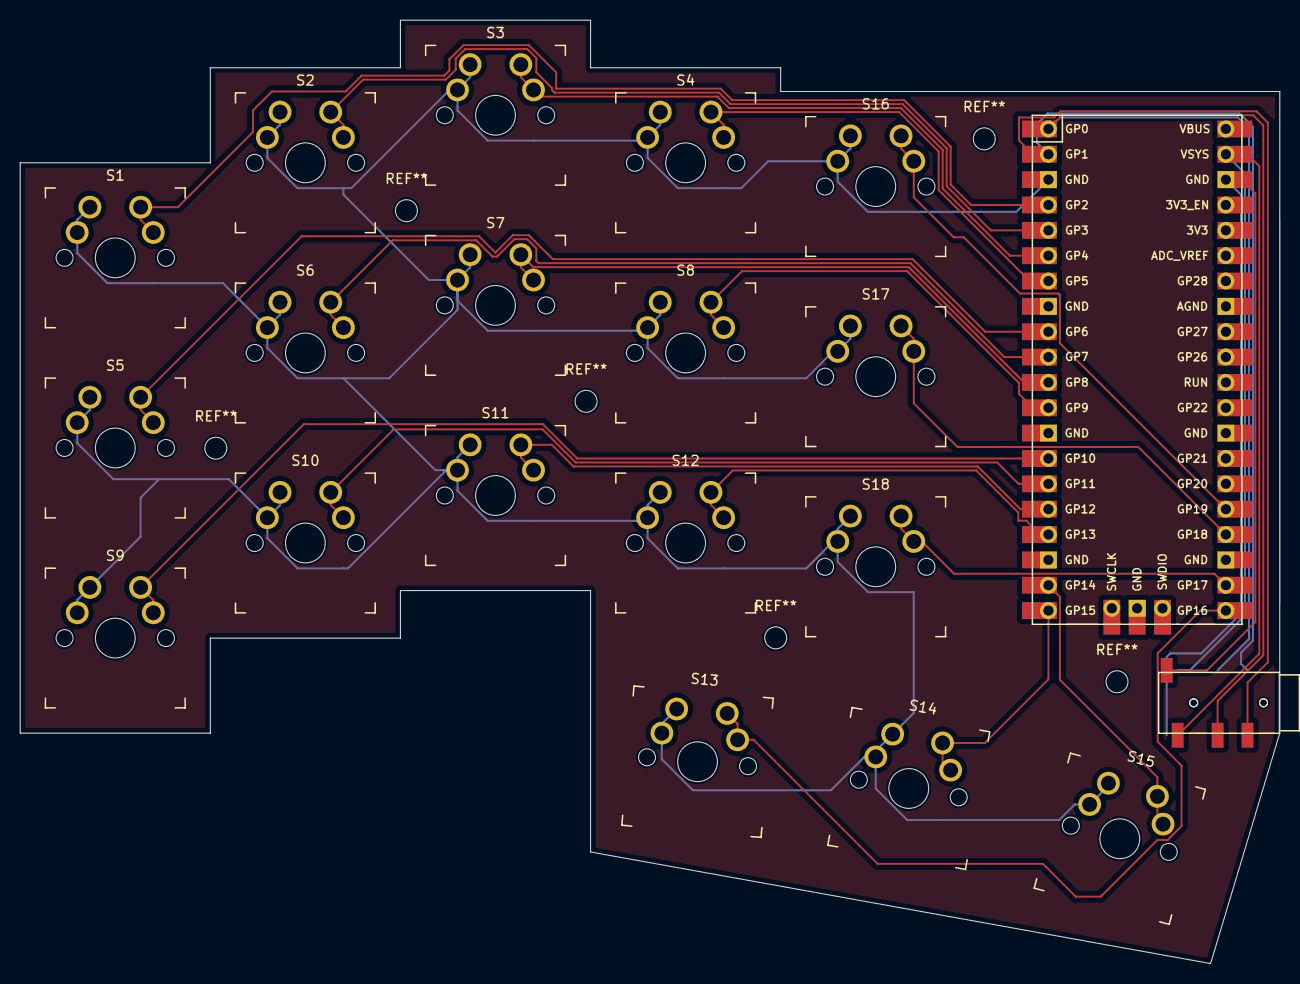
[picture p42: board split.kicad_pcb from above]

Board: 2 copper layers, 126.2 x 94.5 mm, 21 parts (1 on the bottom side), 23 nets.

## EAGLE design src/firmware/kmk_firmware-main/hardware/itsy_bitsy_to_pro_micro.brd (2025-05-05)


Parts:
FRAME2: FRAME-LETTER; CREATIVE_COMMONS
JP1: HEADER-1X570MIL; 1X05_ROUND_70
JP2, JP4: HEADER-1X14; 1X14_ROUND70
JP3, JP5: M12PTH; 1X12

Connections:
!RESET: JP3.3, JP4.14
+3V3: JP4.13
A0: JP3.5, JP4.10
A1: JP3.6, JP4.9
A2: JP3.7, JP4.8
A3: JP3.8, JP4.7
A4: JP3.9, JP4.6
A5: JP3.10, JP4.5
AREF: JP4.12
D2: JP4.1
D3: JP1.4
D4: JP1.5
D5_5V: JP2.10
D7: JP2.9, JP5.1
D9: JP2.8, JP5.2
D10: JP2.7, JP5.3
D11: JP2.6, JP5.4
D12: JP2.5, JP5.5
D13: JP2.4, JP5.6
EN: JP1.1
GND: JP2.2, JP3.2, JP5.9, JP5.10
MISO: JP4.2
MOSI: JP3.12, JP4.3
RAW_PM: JP3.1
RX_D0: JP2.14, JP5.11
SCK: JP3.11, JP4.4
SCL: JP2.11, JP5.7
SDA: JP2.12, JP5.8
SWCLK: JP1.3
SWDIO: JP1.2
TX_D1: JP2.13, JP5.12
VBAT: JP2.1
VBUS: JP2.3, JP3.4
VHI: JP4.11

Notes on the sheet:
TX0/PD3->TX RX1/PD2->RX GND->GND GND->GND 2/PD1->SDA 3/PD0->SCL 4/PD4->13 5/PC6->12 6/PD7->11 7/PE6->10 8/PB4->9 9/PB5->7
OLD
Raw-> GND->GND RST->RST VCC->USB A3/PF4->A0 A2/PF5->A1 A1/PF6->A2 A0/PF7->A3 15/PB1->A4 14/PB3->A5 16/PB2->SCK 10/PB6->MOSI
Bryan Siepert



Board: 2 copper layers, 35.8 x 20.7 mm, 6 parts (2 on the bottom side), 21 nets.

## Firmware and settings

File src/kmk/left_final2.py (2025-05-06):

import board

from kmk.kmk_keyboard import KMKKeyboard
from kmk.keys import KC
from kmk.scanners.keypad import KeysScanner

from kmk.modules.holdtap import HoldTap, HoldTapRepeat
from kmk.modules.layers import Layers
from kmk.modules.mouse_keys import MouseKeys
from kmk.modules.macros import Macros
from kmk.modules.tapdance import TapDance
from kmk.modules.sticky_keys import StickyKeys

from kmk.modules.split import Split, SplitSide, SplitType

split = Split(
    split_type=SplitType.UART,
    split_side=SplitSide.LEFT,
    split_target_left=True,
    data_pin=board.GP0,
    data_pin2=board.GP1,
    use_pio=True,
    uart_flip=True,
    split_flip=False,
)

_KEY_CFG = [
    board.GP2,  board.GP3,  board.GP4, board.GP5, board.GP19,
    board.GP6,  board.GP7,  board.GP8, board.GP9, board.GP18,
    board.GP10, board.GP11, board.GP12, board.GP13, board.GP17,
    board.GP16, board.GP15, board.GP14
]

class MyKeyboard(KMKKeyboard):
    def __init__(self):
        super().__init__()
        self.matrix = KeysScanner(
            pins=_KEY_CFG,
            value_when_pressed=False,
            pull=True,
        )
        self.coord_mapping = [
         0,  1,  2,  3,  4,
         5,  6,  7,  8,  9,
        10, 11, 12, 13, 14,
                15, 16, 17,
        18, 19, 20, 21, 22,
        23, 24, 25, 26, 27,
        28, 29, 30, 31, 32,
        33, 34, 35
        ]

keyboard = MyKeyboard()
layers = Layers()
holdtap = HoldTap()
holdtap.tap_time = 200
macros = Macros()
tapdance = TapDance()
tapdance.tap_time = 200
mousekeys = MouseKeys(
    max_speed = 15,
    acc_interval = 15,
    move_step = 1
)
sticky_keys = StickyKeys(release_after=10000)
keyboard.modules.append(split)
keyboard.modules.append(layers)
keyboard.modules.append(holdtap)
keyboard.modules.append(macros)
keyboard.modules.append(tapdance)
keyboard.modules.append(mousekeys)
keyboard.modules.append(sticky_keys)

keyboard.keymap = [
    [
        # LEFT HALF
        KC.Q, KC.W, KC.E, KC.R, KC.T,
        KC.A, KC.S, KC.D, KC.F, KC.G,
        KC.Z, KC.X, KC.C, KC.V, KC.B,
                        KC.HT(KC.ESC, KC.MO(2)), KC.HT(KC.TAB, KC.LSHIFT), KC.BSPC,
                        # KC.HT(KC.ESC, KC.LCTRL), KC.HT(KC.TAB, KC.LSHIFT), KC.HT(KC.BSPC, KC.LGUI, repeat=HoldTapRepeat.TAP),

        # RIGHT HALF (mirrored layout)
                        KC.Y, KC.U, KC.I, KC.O, KC.P,
                        KC.H, KC.J, KC.K, KC.L, KC.SCLN,
                        KC.N, KC.M, KC.COMM, KC.DOT, KC.SLSH,
        KC.SPACE, KC.HT(KC.ENTER, KC.MO(1)), KC.HT(KC.ESCAPE, KC.MO(3)),
    ],
    [
        KC.NO, KC.NO, KC.C, KC.NO, KC.NO,
        KC.LCTRL, KC.LSHIFT, KC.LALT, KC.LGUI, KC.CAPS,
        KC.NO, KC.NO, KC.NO, KC.NO, KC.NO,
                      KC.NO, KC.NO, KC.NO,

        KC.DOT, KC.N7, KC.N8, KC.N9, KC.N0,
        KC.PLUS, KC.N4, KC.N5, KC.N6, KC.ASTERISK,
        KC.MINUS, KC.N1, KC.N2, KC.N3, KC.SLSH,
        KC.NO, KC.NO, KC.NO,
    ],
    [
        KC.NO, KC.NO, KC.UP, KC.NO, KC.NO,
        KC.NO, KC.LEFT, KC.DOWN, KC.RIGHT, KC.NO,
        KC.NO, KC.NO, KC.NO, KC.NO, KC.NO,
        KC.NO, KC.NO, KC.NO,

        KC.NO, KC.MB_LMB, KC.MS_UP, KC.MB_RMB, KC.NO,
        KC.MW_UP, KC.MS_LT, KC.MS_DN, KC.MS_RT, KC.NO,
        KC.MW_DOWN, KC.NO, KC.NO, KC.NO, KC.NO,
                      KC.NO, KC.NO, KC.NO
    ],
    [
        KC.NO, KC.LABK, KC.RABK, KC.LCBR, KC.RCBR,
        KC.PERCENT, KC.CIRCUMFLEX, KC.AMPERSAND, KC.ASTERISK, KC.UNDERSCORE,
        KC.TILDE, KC.EXCLAIM, KC.AT, KC.HASH, KC.DOLLAR,
                      KC.NO, KC.LEFT_PAREN, KC.RIGHT_PAREN,

        KC.PLUS, KC.LBRC, KC.RBRC, KC.SCLN, KC.COLON,
        KC.MINUS, KC.LABK, KC.RABK, KC.QUOTE, KC.DQT,
        KC.EQUAL, KC.BSLS, KC.PIPE, KC.NO, KC.NO,
        KC.NO, KC.NO, KC.NO,
    ]
]

if __name__ == '__main__':
    keyboard.go()

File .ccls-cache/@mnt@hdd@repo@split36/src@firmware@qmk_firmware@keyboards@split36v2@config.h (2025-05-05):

#pragma once

#define VENDOR_ID 0xFEED
#define PRODUCT_ID 0x6060
#define DEVICE_VER 0x0001
#define MANUFACTURER your_name
#define PRODUCT split36

#define MATRIX_ROWS 8
#define MATRIX_COLS 5

#define DIODE_DIRECTION COL2ROW

#define SOFT_SERIAL_PIN GP1
#define SPLIT_HAND_PIN GP0

#define MASTER_LEFT
// #define MASTER_RIGHT
// #define EE_HANDS

#define USE_SERIAL
// #define USE_I2C

#define RP2040_BOOTLOADER_DOUBLE_TAP_RESET
#define RP2040_BOOTLOADER_DOUBLE_TAP_RESET_LED GP25

#define DIRECT_PINS                                                                                                                                                                      \
    {                                                                                                                                                                                    \
        {GP19, GP5, GP4, GP3, GP2}, {GP18, GP9, GP8, GP7, GP6}, {GP17, GP13, GP12, GP11, GP10}, {NO_PIN, GP16, GP15, GP14, NO_PIN}, {GP2, GP3, GP4, GP5, GP19}, /* right side flipped */ \
            {GP6, GP7, GP8, GP9, GP18}, {GP10, GP11, GP12, GP13, GP17}, {                                                                                                                \
            NO_PIN, GP14, GP15, GP16, NO_PIN                                                                                                                                             \
        }                                                                                                                                                                                \
    }

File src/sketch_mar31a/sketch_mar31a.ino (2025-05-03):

#include <Keyboard.h>

int pins[] = {
  2, 3, 4, 5, 19,
  6, 7, 8, 9, 18,
  10, 11, 12, 13, 17,
          16, 15, 14
};

const int num_pins = sizeof(pins) / sizeof(pins[0]);

int mapping[] = {
  'q', 'w', 'e', 'r', 't',
  'a', 's', 'd', 'f', 'g',
  'z', 'x', 'c', 'v', 'b',
            KEY_RETURN, KEY_BACKSPACE, ' '
};

bool key_down[num_pins];
unsigned long last_press_time[num_pins];
const unsigned long repeat_delay = 1;
const unsigned long initial_delay = 250;

void setup() {
  for (int i = 0; i < num_pins; i++) {
    pinMode(pins[i], INPUT_PULLUP);
    key_down[i] = false;
    last_press_time[i] = 0;
  }
}


void loop() {
  for (int i = 0; i < num_pins; i++) {
    if (digitalRead(pins[i]) == LOW) {
      if (!key_down[i]) {
        Keyboard.write(mapping[i]);
        key_down[i] = true;
        last_press_time[i] = millis();
      } else {
        unsigned long current_time = millis();
        if (current_time - last_press_time[i] > initial_delay) {
          Keyboard.write(mapping[i]);
          last_press_time[i] = current_time;
        }
      }
    } else {
      key_down[i] = false;
    }
  }
  delay(10);
}

// arduino-cli compile --fqbn rp2040:rp2040:rpipicow sketch_mar31a.ino
// arduino-cli upload -p /dev/ttyACM0 --fqbn rp2040:rp2040:rpipicow sketch_mar31a.ino

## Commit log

2025-02-13 bom updated
2025-02-19 major advancements in case building
    [case_bottom.scad, case_middle.scad, first_try_case.FCStd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]
2025-02-19 switched mx dimension images
2025-02-19 offical mx switch dimension image found
2025-02-19 simple case almost done
    [case.scad, case_middle_v2.scad]
2025-02-19 done with the simple case
    [case.scad, case.stl]
2025-02-19 readme updated to include the simple case photos
2025-02-21 pushed the cheaper single case
    [DSA_Keycap_CherryMX.step, Kailh Polia.step, case.scad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]
2025-02-21 order placed for the case
2025-02-26 simple case received but tolerance issue
    [case.scad]
2025-03-25 reordered case with padding
    [case.scad, case_1mm_tolerance.stl]
2025-03-25 added BOM
2025-03-25 updated BOM
2025-03-28 assembling done
    [case.scad]
2025-03-31 purple keycaps and source code pushed
    [right_case.scad, right_case.stl]
2025-04-11 resolving a hurdle
    [bom.csv, case.scad, case.stl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]
2025-05-05 firmware finally done
    [itsy_bitsy_to_pro_micro.brd, itsy_bitsy_to_pro_micro.sch, kmkpython_ref.tsv]

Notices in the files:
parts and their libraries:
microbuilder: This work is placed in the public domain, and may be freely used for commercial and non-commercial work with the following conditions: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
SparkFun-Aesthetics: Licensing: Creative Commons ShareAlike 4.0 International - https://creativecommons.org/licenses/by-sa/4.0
